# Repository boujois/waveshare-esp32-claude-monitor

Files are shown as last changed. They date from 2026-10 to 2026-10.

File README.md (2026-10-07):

# Waveshare ESP32 Claude Monitor

A tiny round desk display that tells you what [Claude Code](https://claude.com/claude-code) is up to, and taps you on the shoulder the moment it needs you. 👋

When a session is waiting for a permission, an answer or a plan approval, the screen lights up with a pulsing orange ring so you never leave Claude sitting idle. The rest of the time it shows which sessions are working, how much of your plan you've used, and what you've got done today.

<p align="center">
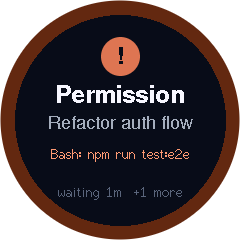
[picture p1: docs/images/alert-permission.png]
Permission alert: pulsing orange ring, 'Permission', session name and the command being requested
  
  &nbsp;
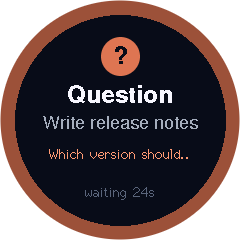
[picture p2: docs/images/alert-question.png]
Question alert: Claude is asking a question in the 'Write release notes' session
  
  &nbsp;
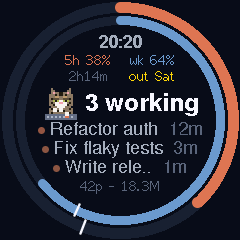
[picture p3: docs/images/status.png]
Status screen: time, plan usage rings with pace ticks, the cat typing beside '3 working', and a list of sessions with timers
  
  &nbsp;
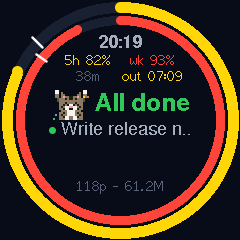
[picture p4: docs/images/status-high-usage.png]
Status screen with high usage: rings turn yellow and red, and the cat cheers beside 'All done'
  
</p>

<p align="center"><sub>Real screenshots, grabbed straight off the device (with made-up session names).</sub></p>

<p align="center"><b><a href="#install">⬇️ Install it: three ways, easiest first</a></b></p>

---

## Contents

- [What it shows](#what-it-shows)
- [What you'll need](#what-youll-need)
- [How it works](#how-it-works)
- [Install](#install)
  - [Option 1: Let Claude set it up (easiest)](#option-1-let-claude-set-it-up-easiest)
  - [Option 2: Download the installer (no coding)](#option-2-download-the-installer-no-coding)
  - [Option 3: Build it yourself, step by step](#option-3-build-it-yourself-step-by-step)
- [Updating](#updating)
- [Reading the screen](#reading-the-screen)
- [Configuration](#configuration)
- [Troubleshooting](#troubleshooting)
- [Privacy: what it reads and where data goes](#privacy-what-it-reads-and-where-data-goes)
- [Uninstalling](#uninstalling)
- [Also in this repo](#also-in-this-repo)
- [Project layout](#project-layout)
- [Credits](#credits)

---

## What it shows

**🟠 When Claude needs you**, the whole screen becomes an alert:

- **What kind of request it is:** *Permission*, *Question*, *Plan ready* or *Needs input*
- **Which session** is asking, by name
- **What it wants**, e.g. `Bash: npm run test:e2e`, or the question Claude is asking
- **How long it's been waiting**, and how many other sessions are waiting too

The alert clears itself as soon as you respond, so you don't need to touch the device. To hide it sooner, **double-tap the case**.

**⚪ The rest of the time**, you get a calm status screen:

- 🕐 The current time
- 🔶 **5-hour plan usage** (outer ring) and 🔷 **weekly plan usage** (inner ring), each with a countdown to its reset and a tick showing whether you're on pace
- **How many sessions are working**, plus up to three active ones, each with a status dot and how long it's been working
- 🐱 **A little tabby cat** beside the headline, acting out what's going on: typing while sessions work, waving when something needs you, cheering when they've finished, and curled up asleep when nothing's happening
- 📊 **Today's activity**: prompts sent and tokens processed, across every session
- 🔴 **Anthropic incidents**: when [Anthropic's status page](https://status.claude.com) reports a problem with Claude Code, the API or claude.ai, a red ring and the incident's name take the place of your plan usage, so you can tell when errors are on Anthropic's side

**🟢 While CI runs** on the pull request for the session you have open in the Claude app, the display shows its checks as a ring that fills in as they pass.

It works with every Claude Code session on your Mac: the desktop app, the terminal and IDE extensions. It can also alert you when a **regular chat in the Claude app** needs you, either to approve a connector or tool, or to answer a question Claude has asked (see [step 7](#7-optional-alerts-for-claude-app-chats)).

---

## What you'll need

| | |
|---|---|
| 🖥️ **The display** | [Waveshare ESP32-S3-LCD-1.28](https://www.waveshare.com/wiki/ESP32-S3-LCD-1.28): an ESP32-S3 with a 1.28" 240×240 round screen (GC9A01). The version with the CNC metal case ("-B") looks great on a desk. Get the **non-touch** version; the touch version uses different pins. |
| 🔌 **A USB-C cable** | For flashing, and for power afterwards. Once it's set up, any USB phone charger will do. |
| 🍎 **A Mac** | Running Claude Code. The helper uses `launchd` and the macOS Keychain. |
| 📶 **2.4 GHz Wi-Fi** | The ESP32 can't join 5 GHz-only networks. |
| 🌐 **Chrome or Edge** | For the one-click firmware installer. Safari and Firefox can't talk to USB devices. |
| 🐍 **Python 3** | For the Mac helper. macOS has it once Apple's Command Line Tools are installed; the installer offers to install them if needed. |
| 🐙 **Optional: the [GitHub CLI](https://cli.github.com)** | For the [CI card](#the-ci-card): `brew install gh`, then `gh auth login` |
| 🛠️ **[PlatformIO](https://platformio.org/install/cli)** | *Developers only*, to build the firmware yourself: `brew install platformio` |
| 🖨️ **Optional: a 3D printer** | To print a [desk stand](#-stand-3d-printable-desk-stands). You'll also want a right-angle USB-C cable. Four 8 × 2 mm button magnets are optional, if you'd like to stick the stand to a metal surface. |

---

## How it works

```mermaid
flowchart LR
    subgraph Mac["Your Mac"]
        CC["Claude Code sessions<br/>(desktop app, terminal, IDE)"]
        S["~/.claude/sessions/*.json<br/>(live session list)"]
        T["~/.claude/projects/**/*.jsonl<br/>(transcripts)"]
        B["Mac helper<br/>claude_status_bridge.py"]
        CC -- "hooks (async curl)" --> B
        CC -.writes.-> S
        CC -.writes.-> T
        S --> B
        T --> B
        CH["Claude app chats"]
        L["chat-window log<br/>(tool approvals)"]
        CH -.writes.-> L
        L --> B
        CH -- "claude-status connector<br/>(waiting_for_user)" --> B
    end
    A["Anthropic usage API<br/>(optional)"] --> B
    G["GitHub CI checks<br/>(via gh, optional)"] --> B
    SP["Anthropic status page<br/>(incidents)"] --> B
    B -- "POST /state over Wi-Fi<br/>(every second when changed)" --> D["Round display<br/>claude-status.local"]
```

There are three main moving parts, plus an extra for chats:

1. **Claude Code hooks** fire on events like *permission requested*, *question asked*, *tool finished* and *turn finished*. Each hook is a tiny background `curl` that forwards the event to the helper on `127.0.0.1`. The hooks are async, so they never slow Claude down, and they quietly do nothing if the helper isn't running.
2. **The Mac helper** (`claude-status/bridge/claude_status_bridge.py`) merges three sources into one small JSON summary:
   - **the hook events**, to work out who's waiting for you
   - **`~/.claude/sessions/`**, for which sessions are open and whether each is busy or idle
   - **your transcripts**, for today's token and prompt totals

   If you turn it on, it also checks your plan usage with Anthropic. If the GitHub CLI is signed in, it asks GitHub about the checks on the pull request for the session you have open in the Claude app. Every 2 minutes it checks Anthropic's status page for incidents. It pushes the summary to the display whenever something changes, plus a heartbeat every 10 seconds.
3. **The display firmware** (`claude-status/firmware/`) joins your Wi-Fi and announces itself as `claude-status.local`. It accepts the summary on `POST /state` and draws the right screen at about 30 fps.
4. **Chats in the Claude app** don't have hooks, so the helper uses two other signals. It watches the app's chat-window log for **tool approval prompts**. A tiny local **connector** (`chat_mcp.py`) also gives Claude a `waiting_for_user` tool, which it calls when a reply ends with a question for you.

---

## Install

There are three ways to install, easiest first:

| | Best for | You'll need |
|---|---|---|
| 🤖 **[Option 1: Let Claude set it up](#option-1-let-claude-set-it-up-easiest)** | Anyone who uses Claude Code | Claude Code: the Claude app's **Code** tab, or `claude` in a terminal |
| ⬇️ **[Option 2: Download the installer](#option-2-download-the-installer-no-coding)** | No coding, and no Claude Code needed | Google Chrome or Microsoft Edge |
| 🛠️ **[Option 3: Build it yourself](#option-3-build-it-yourself-step-by-step)** | Developers who want to change the code | PlatformIO and a terminal |

All three need the display, a USB-C **data** cable (many charging-only cables won't work) and a Mac.

---

## Option 1: Let Claude set it up (easiest)

Claude Code does the whole setup for you, using the [setup skill](.claude/skills/setup-claude-monitor/SKILL.md) included in this project:
- it checks your Mac and installs the tools it needs
- it flashes the display and walks you through Wi-Fi on your phone
- it sets up your Mac and tests everything end to end

It stops and tells you whenever a step needs you, such as clicking **Always Allow** on a Keychain prompt.

1. **Get the project.** Download **Source code (zip)** from the [latest release](https://github.com/boujois/waveshare-esp32-claude-monitor/releases/latest) and double-click it to unzip. If you use git, you can clone it instead:
   ```bash
   git clone https://github.com/boujois/waveshare-esp32-claude-monitor.git
   ```
2. **Plug the display into your Mac** with the USB-C cable.
3. **Open the folder in Claude Code:**
   - **Claude app:** open the **Code** tab and choose the unzipped folder as the project.
   - **Terminal:** `cd` into the folder and run `claude`.
4. **Say *"set up the display"*,** or type `/setup-claude-monitor`, then follow along.

Allow about 10 minutes. Claude flashes the published firmware, the same files as Option 2, so there's nothing to build unless you ask it to build from source. The rest follows the same steps as [Option 3](#option-3-build-it-yourself-step-by-step), so you can read along there.

---

## Option 2: Download the installer (no coding)

No coding, no command line, about 10 minutes. Use **Google Chrome** or **Microsoft Edge** for step 1.

### 1. Put the software on the display

Open the **[Claude Monitor installer](https://boujois.github.io/waveshare-esp32-claude-monitor/)** in Chrome or Edge. Plug the display into your computer, click **Install Claude Monitor**, choose the display from the list, then click **Install**. It takes about a minute.

<details>
<summary><b>The installer page doesn't open?</b> Use Espressif's web flasher instead</summary>

1. Download **`claude-monitor-firmware.bin`** from the [latest release](https://github.com/boujois/waveshare-esp32-claude-monitor/releases/latest).
2. Open [Espressif's web flasher](https://espressif.github.io/esptool-js/) in Chrome or Edge.
3. Click **Connect** and choose the display.
4. Set **Flash Address** to `0x0`, choose the `.bin` file, then click **Program**.
5. When it's done, unplug the display and plug it back in.
</details>

### 2. Connect the display to your Wi-Fi

The display now shows **Wi-Fi setup** with a QR code. On your phone, scan the code, or join the Wi-Fi network **`Claude-Monitor-Setup`**. A page pops up: pick your home Wi-Fi, type its password, and tap **Save**. The display connects and shows **"Waiting for Mac"**.

> 📶 The display only works with **2.4 GHz** Wi-Fi. If the page doesn't pop up, open `192.168.4.1` in your phone's browser.

**To change Wi-Fi later**, do any of these:
- unplug the display and plug it back in **3 times in a row**, each within 10 seconds of the last; the second time, it reminds you to do it once more
- run `curl -X POST http://claude-status.local/wifi/reset` on your Mac
- hold the **BOOT** button for 5 seconds, if your case leaves it reachable

If the display can't find its saved Wi-Fi, for example after moving house, it opens setup by itself.

### 3. Set up your Mac

1. Download **`Claude-Monitor-Mac.zip`** from the [latest release](https://github.com/boujois/waveshare-esp32-claude-monitor/releases/latest) and double-click it to unzip.
2. In the **Claude Monitor** folder, **right-click `Install.command` and choose Open**. macOS blocks double-clicking downloaded scripts the first time. If it still refuses, open **System Settings → Privacy & Security** and click **Open Anyway**.
3. Answer the questions in the window that opens. It asks before restarting the Claude app, and before turning on plan usage.
4. For chat questions, the installer copies one sentence to your clipboard. Paste it into **Claude → Settings → Profile → personal preferences**.

Within a few seconds the display switches to your Claude status. To remove everything later, right-click **`Uninstall.command`** and choose **Open**.

---

## Option 3: Build it yourself, step by step

For developers, or anyone who wants to see every step. Allow about 15 minutes. Most of that is PlatformIO downloading the ESP32 toolchain the first time.

### 1. Clone the repo

```bash
git clone https://github.com/boujois/waveshare-esp32-claude-monitor.git
cd waveshare-esp32-claude-monitor
```

### 2. Wi-Fi (optional for development)

You don't need to put your Wi-Fi details in the code: after flashing, set up Wi-Fi from your phone as in [Option 2, step 2](#2-connect-the-display-to-your-wi-fi). The display remembers it across re-flashes.

If you re-flash a lot and want to skip that step, you can pre-fill your Wi-Fi in a git-ignored `src/secrets.h`:

```bash
cp claude-status/firmware/src/secrets.h.example claude-status/firmware/src/secrets.h
```

It's only used when the board has no saved network, and release builds never include it.

### 3. Flash the display

Plug the board into your Mac with USB-C, then build and upload. PlatformIO finds the board by itself. If you have several boards plugged in, add `upload_port = /dev/cu.usbmodem…` to `platformio.ini`.

```bash
cd claude-status/firmware
pio run -t upload
```

The first build downloads the ESP32-S3 toolchain plus the [LovyanGFX](https://github.com/lovyan03/LovyanGFX) and [ArduinoJson](https://arduinojson.org/) libraries, so give it a few minutes. When it finishes, the display shows **Wi-Fi setup**, or **"Waiting for Mac"** if it already knows your Wi-Fi. 🎉

> 💡 **Tip:** `pio device monitor` shows the board's serial log, including `Wi-Fi connected, IP …` and `mDNS: claude-status.local`.

### 4. Install the Mac helper and hooks

```bash
cd ../bridge
./install.sh
```

This does three things:

- **Starts the helper as a background service** (`~/Library/LaunchAgents/com.claude-status.bridge.plist`). It starts when you log in and restarts itself if it ever crashes.
- **Adds the hooks to `~/.claude/settings.json`**, after saving a timestamped backup next to it. Your existing settings and hooks are left as they are. Ours are tagged with `CLAUDE_STATUS` so they can be found and removed cleanly later.
- **Adds the `claude-status` connector to the Claude app** (`claude_desktop_config.json`, also backed up first) for [chat alerts](#7-optional-alerts-for-claude-app-chats). The app overwrites that file while it's running, so if the app is open, the installer skips this step and tells you to run `./install-chat-connector.sh` from **Terminal.app** instead. That script quits the Claude app, adds the connector and reopens the app; your sessions are still there afterwards.

> ℹ️ The installer finds Python by itself (Homebrew's, or the one that comes with Apple's Command Line Tools). To use a specific one, run `PYTHON=/path/to/python3 ./install.sh`.

Within a couple of seconds the display should switch from *"Waiting for Mac"* to the status screen. New Claude Code sessions pick up the hooks automatically, and most already-open sessions do too.

### 5. Try it out ✅

Ask Claude something that needs your approval, or just ask it to *"ask me a question"*. The display should light up orange straight away, and go back to normal when you answer.

### 6. (Optional) Turn on plan usage rings

The rings show your 5-hour and weekly plan limits, the same numbers as Claude Code's `/usage` screen. They use the sign-in of the **terminal** `claude` command. The desktop app keeps its own separate sign-in, so you need to sign the terminal in once.

**a. Sign the terminal in.** This opens your browser:

```bash
claude auth login
```

**b. Switch plan usage on and restart the helper:**

```bash
echo '{"plan_usage": true}' > config.json
```
```bash
launchctl kickstart -k gui/$(id -u)/com.claude-status.bridge
```

**c. Allow Keychain access.** macOS will ask whether `security` can read **"Claude Code-credentials"**. Click **Always Allow**. If you click plain *Allow*, it will ask again after every restart.

The rings fill in within a few seconds and refresh every 5 minutes.

**Keeping it signed in:** the sign-in token expires every few hours. When it does, the helper asks the `claude` command to renew it by sending one tiny prompt (`ok`) on Haiku. That prompt runs with no tools, connectors, hooks or saved session, so it uses a negligible sliver of your plan. You'll see `plan usage: token renewed` in the log when it happens. You should only need `claude auth login` again if you sign out, or if the sign-in is revoked.

> 🔒 The token is only ever sent to `api.anthropic.com`. The helper never refreshes, rewrites or logs it. Renewal is done by the `claude` command itself.

> 💡 **Why not a long-lived `claude setup-token` token?** We tried: Anthropic accepts those tokens but refuses them for plan usage (HTTP 403).

### 7. (Optional) Alerts for Claude app chats

Regular chats in the Claude app (the **Chat** tab, not Claude Code) can light up the display too. There are two kinds of alert.

**🔐 Tool approvals work automatically.** When a chat shows an **Allow** button for a connector or tool, the display shows **Permission → Claude chat → "Allow Weather: get_forecast?"**. There's nothing to set up.

**❓ Questions need one line in your Claude settings.** The `claude-status` connector from step 4 gives Claude a `waiting_for_user` tool. To make sure Claude uses it:

1. Make sure the connector is installed. If `install.sh` said the Claude app was running, run this from **Terminal.app**, not a terminal inside the Claude app:

   ```bash
   ./install-chat-connector.sh
   ```
2. Open **Settings → Profile**, and add this to *"What personal preferences should Claude consider in responses?"*:

   > When a reply ends with a question for me, or you need me to choose or decide something before you can continue, call the claude-status `waiting_for_user` tool as the last step, with a short version of the question and a 2-5 word title for the chat.

3. The first time Claude calls it, choose **Always allow**.

The display then shows **Question → *chat title* → *the question***.

**How chat alerts clear:** the app doesn't report when you've answered, so a chat alert clears in any of these cases:
- when you **switch to the Claude app**
- after the app has been **in front for 30 seconds**, if you were already in it
- when the chat's **next tool runs** without needing approval (approval alerts only)
- **after 10 minutes**, as a backstop

> ⚠️ **Good to know:**
> - Question alerts rely on Claude choosing to call the tool. That's usually reliable, but not guaranteed.
> - Tool approvals are read from the app's internal log, so an app update could quietly change or break them.
> - Neither works for claude.ai open in a web browser.

---

## Updating

When a new version comes out, the display's footer alternates with **"Update: v1.x.x"**. The helper checks GitHub once a day. To update, do any of these:

- **Ask Claude Code** *"update my Claude monitor"*. The installer adds an `update-claude-monitor` skill to Claude Code, so this works in any session.
- **Double-click** `Update.command` from the Mac zip; the first time, right-click it and choose **Open**.
- **Run** `"$HOME/Library/Application Support/Claude Monitor/update.sh"` in a terminal. Add `--check` to only see the versions.

It updates the Mac helper, keeping your settings, and sends the new firmware to the display **over Wi-Fi**. No cable is needed; the display shows a progress ring and restarts by itself.

> 🔐 **Pairing:** the first time the helper finds the display, they pair with a random key. After that, only your Mac can update the display. To pair with a different Mac, power the display on 3 times in a row, each within 10 seconds of the last. That resets its Wi-Fi and pairing.

> ⚠️ **Coming from v1.0.x?** Older displays can't update over Wi-Fi yet, and older Mac installs don't have `update.sh`. Do one last manual update: re-flash from the [installer page](https://boujois.github.io/waveshare-esp32-claude-monitor/), which keeps your Wi-Fi, and run `Install.command` from the new zip. Every update after that is automatic.

---

## Reading the screen

### The status screen

Status screen

From top to bottom:

- **Rings:** the outer 🔶 ring is your 5-hour plan usage and the inner 🔷 ring is weekly usage. They fill clockwise from 12 o'clock. The small white **tick** on each ring shows how much of that window has gone by. If the coloured arc is past its tick, you're using your plan faster than it lasts. While Anthropic has an incident affecting Claude Code, the API or claude.ai, the usage rings make way for a pulsing **red** ring, and *Anthropic incident* shows where the usage numbers were, with the incident's name scrolling underneath, e.g. *Elevated errors for Claude Opus 5.5*. Red error dots are then most likely Anthropic's problem, not yours.
- **Time:** the current time, kept in sync over the internet (NTP).
- **`5h 38%` / `wk 64%`:** the same usage as numbers, with the time left until each limit resets underneath. When you're ahead of the tick, it shows in yellow when you'd run out at this pace instead: `out 16:40`, or `out Fri` for the weekly limit.
- **Headline**, with [the cat](#the-cat) acting it out beside it:
  - **`2 working`:** sessions are busy
  - **`All done`** (green): sessions have finished; you'll usually see the green Done card instead
  - **`All idle`:** nothing is happening
  - **`1 waiting`** (pulsing orange): you dismissed an alert, but something still needs you
- **Session list:** up to three active sessions, each with a dot (see the colour guide below). Working sessions show how long they've been working, e.g. `12m`.
- **Footer:** today's prompt count and total tokens processed, across all sessions.

<br clear="right">

### The cat

<p align="center">The cat's five moods: typing at a keyboard, waving a paw, cheering with its paws in the air, seeing stars, and curled up asleep</p>

A brown tabby sits beside the headline on the status screen and acts out what your sessions are up to:

| The cat is… | When |
|---|---|
| ⌨️ **Typing** | Sessions are working (`2 working`). The more there are, the faster it types. |
| 👋 **Waving** | Something still needs you after you hid its alert (`1 waiting`) |
| 🎉 **Cheering** | Sessions have finished and you haven't replied yet (`All done`) |
| 💫 **Seeing stars** | A session's last turn ended with an API error, and nothing is working or waiting |
| 💤 **Asleep** | Nothing is happening (`All idle`), or the display hasn't heard from your Mac |

When the display powers on, the cat walks across the empty screen before anything else appears.

Prefer the plain status screen? Set `"cat": false` in the helper's `config.json` (see [Configuration](#configuration)). The display remembers it, so the walk at power-on stops too.

### The alert screen

Question alert

| Headline | Badge | Shown when… |
|---|---|---|
| **Permission** | `!` | Claude wants to run a tool that needs your approval |
| **Question** | `?` | Claude is asking you a multiple-choice question, or its reply ends waiting on you: a question (*"Want me to push it?"*), a request (*"After you approve, I'll create the ticket"*), or a step for you to do (*"Run it on staging and paste the output"*) |
| **Plan ready** | `!` | Claude has finished a plan and wants you to review it |
| **Needs input** | `!` | an MCP server or agent needs something from you |

If several sessions are waiting, the one that has waited longest is shown, and the footer says `+N more`.

**Want it to go away?** Double-tap the case: two quick, firm taps with a fingertip, anywhere on the case. A short press of the **BOOT** button does the same, if your case leaves it reachable. That hides the alert until a *new* request comes in, and the status screen then shows `N waiting` in orange instead.

Double tap uses the board's built-in motion sensor. Typing, putting a mug down or knocking on the desk doesn't set it off, and neither does picking the display up.

<br clear="right">

### The Done card

When a Claude Code session finishes and doesn't need anything from you, the display shows a green **Done** card: a ✓, the session's name, a one-line summary of what it did (from the [reply check](#how-replies-that-need-you-are-spotted)), and how long ago it finished. The card stays until you send that session another message, so you can see at a glance that a task is finished. If several sessions have finished, the most recent is shown with `+N more`.

The card goes away when:
- **you reply** to that session
- **you look at it:** open that session in the Claude app, with the app in front
- **you were already watching:** if the session finishes while it's open in front of you, no card appears
- **you double-tap the case** (or press **BOOT**): the sessions on the card stay hidden, and a session that finishes later still gets its own card

A quick acknowledgement like *"thanks"*, *"ok"* or 👍 doesn't bring the card back when Claude answers it.

Needs-input alerts always come first. If you'd rather finished sessions faded back to the status screen after a while, set `done_window` in `config.json`, for example `900` for 15 minutes.

### The CI card

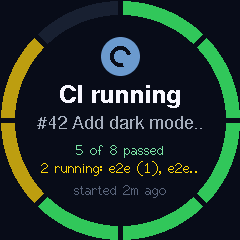
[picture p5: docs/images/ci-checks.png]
CI card: a ring of eight checks, five passed, two running and one queued


When the session you have open in the Claude app is on a branch with an open pull request, the display shows that pull request's checks. The ring has one segment per check and fills clockwise as they pass: 🟢 passed, 🔴 failed, 🟡 running (pulsing), dark for queued and grey for cancelled. Checks that were skipped are left out. Underneath, it says how many have passed, which ones are running or failed, and when the run started or finished.

It follows the session you last opened in the Claude app, so it stays up while you switch to another app to wait. A question or permission request from **another** session still comes first. The CI card then comes before the open session's own requests, which you can see in the app anyway, and before Done cards.

Passed checks stay on screen for 10 minutes, then the status screen comes back (`ci_passed_window` in `config.json`). Failed checks stay until you push again. Double-tap to hide the card until the checks change.

The helper asks GitHub with the [GitHub CLI](https://cli.github.com) (`gh`), every 15 seconds while checks run and every minute otherwise, so `gh` needs to be installed and signed in. Sessions in the terminal or an IDE don't get a CI card: only the Claude app tells the helper which session you have open.

<br clear="right">

### How replies that need you are spotted

When a Claude Code turn ends, the helper reads Claude's final message:

1. **Phrase check.** If the message ends with a question, or a request like *"after you approve"*, *"please confirm"*, *"should I…"* or *"over to you"*, the display shows a **Question** alert straight away.
2. **Haiku check.** If the phrases don't catch it, the helper asks Claude Haiku, through the terminal `claude` command, whether the message is waiting on you, and gets a one-line summary for the display. Each check takes a few seconds and uses a sliver of your plan.

The Haiku check needs the terminal `claude` command to be signed in, the same as the [plan usage rings](#6-optional-turn-on-plan-usage-rings). Without that sign-in, only the phrase check runs. To turn the Haiku check off, set `"check_replies": false` in `config.json`. When the helper starts, it also checks idle sessions from the last 24 hours, so nothing is missed after a restart.

### Colour guide

| Colour | Meaning |
|---|---|
| 🟠 Orange dot (pulsing) | Session is working |
| 🟠 Orange dot (solid) | Session is waiting for you |
| 🟢 Green card / dot | Session finished, and you haven't replied to it yet |
| 🔴 Red dot | Session's last turn ended with an API error |
| 🟡 Yellow ring | Usage is 75% or more |
| 🔴 Red ring | Usage is 90% or more. Time to pace yourself! |
| ⚪ White tick on a usage ring | How much of that window has gone by. Usage past its tick will run out before the reset. |
| 🟡 `out 16:40` | When you'd run out at your current pace |
| 🟢 🔴 🟡 Ring segments | CI checks passed, failed or running, on the [CI card](#the-ci-card) |
| 🔴 Red ring (pulsing) instead of the usage rings | Anthropic has an incident affecting Claude Code, the API or claude.ai |

### Other screens

- **Waiting for Mac:** the display has never heard from the helper since it powered on. It shows its IP address and `claude-status.local` to help with debugging.
- **Mac offline:** nothing has arrived for 30 seconds. Your Mac might be asleep, or the helper might have stopped. The cat naps on both of these screens until the Mac is back.
- **Wi-Fi setup:** the display has no saved Wi-Fi, or can't reach it. Join `Claude-Monitor-Setup` from your phone. See [Option 2, step 2](#2-connect-the-display-to-your-wi-fi) for how to bring this screen back to change networks.
- **Diagnostics:** tap the case **5 times** quickly. It shows the firmware version, the Wi-Fi network and its signal strength, the IP address and name, when the Mac last sent an update, and how long the display has been on. The ring counts down for 30 seconds, then it closes by itself. Double-tap to close it sooner.

---

## Configuration

### Mac helper: `claude-status/bridge/config.json`

All keys are optional, and this file is git-ignored. Restart the helper after changing it:

```bash
launchctl kickstart -k gui/$(id -u)/com.claude-status.bridge
```

| Key | Default | What it does |
|---|---|---|
| `device_host` | `"claude-status.local"` | Hostname or IP of the display |
| `plan_usage` | `false` | Fetch 5-hour/weekly plan usage (see [step 6](#6-optional-turn-on-plan-usage-rings)) |
| `plan_usage_interval` | `300` | Seconds between plan usage checks |
| `push_interval` | `1.0` | How often (seconds) the helper checks for changes |
| `heartbeat_interval` | `10` | Push at least this often (seconds), even if nothing changed |
| `done_window` | `0` | How long (seconds) a finished session shows as done (the green card). `0` keeps it until you reply |
| `chat_alerts` | `true` | Alert on Claude app chats (tool approvals and connector questions) |
| `check_replies` | `true` | When a Claude Code reply doesn't obviously ask for anything, ask Haiku whether it's waiting on you (see [How replies that need you are spotted](#how-replies-that-need-you-are-spotted)) |
| `ci_checks` | `true` | Show the [CI card](#the-ci-card) for the session you have open in the Claude app. Needs the GitHub CLI (`gh`), signed in |
| `ci_passed_window` | `600` | How long (seconds) checks that passed stay on screen. `0` keeps them while the session is open |
| `status_page` | `true` | Check [Anthropic's status page](https://status.claude.com) every 2 minutes, and turn the ring red during incidents affecting Claude Code, the API or claude.ai |
| `cat` | `true` | Show [the cat](#the-cat). `false` brings back the plain status screen, and the display stops walking the cat across at power-on |
| `listen_port` | `47823` | Local port for hooks. If you change it, also update the URL in `hooks.py` and re-run `install.sh` |

### Firmware: top of `claude-status/firmware/src/main.cpp`

| Setting | Default | What it does |
|---|---|---|
| `HOSTNAME` | `"claude-status"` | mDNS name: the display is reachable at `<HOSTNAME>.local` |
| `SETUP_AP` | `"Claude-Monitor-Setup"` | Name of the Wi-Fi setup network |
| `DEFAULT_TZ` | `"UTC0"` | Timezone until the Mac helper connects. After that, the display uses your Mac's timezone automatically. |
| `STALE_MS` | `30000` | How long (ms) without an update before showing *Mac offline* |
| `TAP_G` | `0.25` | How firm each tap on the case must be, in g. Raise it if knocks on your desk dismiss alerts; lower it if your taps are missed. |
| `DIAGNOSTICS_MS` | `30000` | How long (ms) the diagnostics screen stays up after 5 quick taps |
| Brightness | `150` / `255` | Status screen / alert brightness, set at the end of `loop()` |

Re-flash after changing anything with `pio run -t upload`.

---

## Troubleshooting

<details>
<summary><b>The display is stuck on "Waiting for Mac"</b></summary>

1. Is the helper running? `launchctl print gui/$(id -u)/com.claude-status.bridge | grep state` should say `running`.
2. Check its log: `tail -20 ~/Library/Logs/claude-status-bridge.log`. Look for `pushing to claude-status.local (192.168.x.x)`.
3. If it says `cannot resolve claude-status.local`, mDNS isn't getting through your network. Set `"device_host"` in `config.json` to the IP address shown on the display. A DHCP reservation in your router keeps that IP from changing.
4. Make sure your Mac and the display are on the same network. Guest networks often block devices from seeing each other.
</details>

<details>
<summary><b>Claude is waiting but the display doesn't alert</b></summary>

1. Check the hooks are installed: `jq '.hooks | keys' ~/.claude/settings.json` should list `PermissionRequest`, `PreToolUse`, `Notification` and the others.
2. Check events are arriving: `curl -s http://127.0.0.1:47823/state | jq .hook_events_seen` should increase as you use Claude.
3. The helper logs every change to who's waiting, e.g. `9a8ac88a PermissionRequest: waiting - -> ['perm']`.
4. Sessions that were already open before you installed may need restarting to pick up the hooks.
</details>

<details>
<summary><b>An alert won't go away</b></summary>

Alerts clear when the tool finishes, when you send a new prompt, or when Claude's turn ends. If you deny a permission and Claude stops quietly, the alert clears when that turn ends. You can also double-tap the case to dismiss it, or press **BOOT** if your case leaves the button reachable.
</details>

<details>
<summary><b>Double-tapping doesn't dismiss anything</b></summary>

1. Tap the metal case twice with a fingertip, firmly, with the second tap within about half a second of the first. Stop at two: three or four taps in a row don't count. It works on the alert, the CI card and the Done card; the status screen ignores it.
2. Open `http://claude-status.local/` in a browser. `taps seen` counts the double taps and 5-tap runs the display noticed. If it says `no motion sensor`, your board doesn't have one, or it isn't answering.
3. If light taps are missed, or knocks on your desk count, change `TAP_G` in the [firmware settings](#configuration) and re-flash.
</details>

<details>
<summary><b>The CI card doesn't appear</b></summary>

1. It only shows for the session you have open in the **Claude app**, not the terminal or an IDE, and only while that session's branch has an **open** pull request with checks.
2. Passed checks stay for 10 minutes after they finish. To keep them up while the session is open, set `"ci_passed_window": 0` in `config.json`.
3. In that session's folder, `gh pr view --json statusCheckRollup` should list the checks. If `gh` isn't installed, run `brew install gh`. If it says you aren't signed in, run `gh auth login`.
4. The helper logs each change, e.g. `CI #1252 Fix the login form: running PPPRRQ`.
</details>

<details>
<summary><b>The ring is red and my usage is gone</b></summary>

Anthropic's [status page](https://status.claude.com) is reporting an incident that affects Claude Code, the Claude API or claude.ai; its name scrolls under *Anthropic incident* at the top of the status screen. The ring goes back to normal once Anthropic marks the incident resolved. Incidents that only affect other services, such as the Console, don't count. If the helper can't reach the status page for 10 minutes, it stops showing the incident, so a problem with your own connection isn't blamed on Anthropic.
</details>

<details>
<summary><b>The usage rings are empty</b></summary>

- Is `plan_usage` set to `true` in `config.json`? Did you restart the helper afterwards?
- `tail ~/Library/Logs/claude-status-bridge.log`:
  - **`no usable token` / `token rejected`:** run `claude auth login` in a terminal. The helper picks it up within 5 minutes.
  - **`renewal call failed`:** the helper couldn't run `claude`. Check that `claude -p ok` works in a terminal.
  - **`keychain read failed`:** you clicked *Deny* on the Keychain prompt. Restart the helper and click **Always Allow**.
- Plan usage is only available for Claude Pro and Max subscriptions.
</details>

<details>
<summary><b>Chat alerts don't appear</b></summary>

- **Questions:**
  - Check that `claude-status` appears in the chat's connectors (search and tools) menu. If it doesn't, run `./install-chat-connector.sh` from Terminal.app. Editing the config while the app is open doesn't stick.
  - Is the line in your personal preferences? Try asking a chat to *"ask me a question"*.
  - The helper logs `chat: question from …` when the tool is called.
- **Tool approvals:** the helper logs `chat: approval needed for …`. If that never appears, an app update may have changed the log format.
</details>

<details>
<summary><b>Colours look wrong, or the screen is blank</b></summary>

- **Inverted colours** (white background): flip `cfg.invert` in the `LGFX` class in `main.cpp`.
- **Blank screen:** double-check you have the **non-touch** ESP32-S3-LCD-1.28. The touch version uses different reset and backlight pins (RST 14, BL 2).
</details>

<details>
<summary><b>Upload fails with "port is busy" or "no serial data received"</b></summary>

Close anything else using the serial port, such as `pio device monitor` or the Arduino IDE. If it still won't connect, hold **BOOT**, tap **RESET**, release **BOOT**, then upload again.
</details>

### Handy debugging tools 🔧

| What | How |
|---|---|
| See exactly what the helper is sending | `curl -s http://127.0.0.1:47823/state \| jq` |
| One-off snapshot without the service | `python3 claude-status/bridge/claude_status_bridge.py --once` |
| Screenshot of the display | Open `http://claude-status.local/screen.bmp` in a browser |
| Display's own status page, including the taps it has seen | `http://claude-status.local/` |
| Diagnostics on the display itself: version, Wi-Fi, IP | Tap the case 5 times quickly |
| Helper log | `tail -f ~/Library/Logs/claude-status-bridge.log` |

---

## Privacy: what it reads and where data goes

It's your Claude activity, so here's exactly what this project touches:

- **Hooks** send event data (session ID, tool name and tool input such as the command being run) **only to `127.0.0.1`**, the helper on your own Mac.
- **The helper reads** `~/.claude/sessions/` (session names and busy/idle state) and your transcript files in `~/.claude/projects/` (token counts and prompt *counts* only; it doesn't keep your messages).
- **The display receives** session names, short details such as `Bash: npm test`, counts and usage percentages, over your local Wi-Fi.
- **Chat alerts:** the helper reads the Claude app's chat-window log (`~/Library/Logs/Claude/claude.ai-web.log`), but only the tool approval lines, which contain a tool name. The connector sends the short question and chat title Claude gives it to the helper on `127.0.0.1`, and from there to the display.
- **Reply checks:** when a Claude Code turn ends without an obvious question, the last 3,000 characters of Claude's reply are sent to Claude Haiku, through your own `claude` sign-in, to ask whether it's waiting on you. Turn this off with `"check_replies": false`.
- **Plan usage (opt-in only)** reads the terminal `claude` login's token from your Keychain and sends it **only to `api.anthropic.com`**. When the token expires, the helper runs one tiny `claude -p ok` request so the CLI renews it.
- **CI checks:** for the session you have open in the Claude app, the helper runs `gh pr view` in that session's folder, which asks **GitHub** about the branch's pull request using your own `gh` sign-in. The display gets the pull request's number and title, and the names and results of its checks. Turn this off with `"ci_checks": false`.
- **Anthropic's status page:** every 2 minutes the helper downloads the public summary from `status.claude.com`. The request carries nothing about you or your sessions. Turn this off with `"status_page": false`.
- **Nothing else leaves your Mac.** There's no telemetry, cloud service or account.

- **Updates:** the helper checks GitHub's public API for the latest release once a day. Firmware updates only go from your Mac to the display, using the pairing key in `config.json`.

> ⚠️ Apart from firmware updates, which need the pairing key, the display's web endpoints have no password. Anyone on your local network could read the screenshot, push fake status to it or reset its Wi-Fi. That's fine on a home network, but think twice on shared or office Wi-Fi.

---

## Uninstalling

```bash
./claude-status/bridge/uninstall.sh
```

This stops and removes the background service, takes our hooks back out of `~/.claude/settings.json`, removes the `claude-status` connector from the Claude app and the `update-claude-monitor` skill. It saves backups first, and leaves your other hooks and connectors alone. The display then shows *Mac offline* until you re-flash it with something else.

Also remove the `waiting_for_user` line from your Claude personal preferences. To sign the terminal out as well, run `claude auth logout`.

---

## Also in this repo

### 🖨️ `stand/`: 3D-printable desk stands

Desk stands for the CNC-cased display, ready to print. They all hold the screen at the same 75° angle and height, and all leave room for a **right-angle USB-C cable**: the plug sits under the case and the cable runs back through the stand and out of the back.

**Nine designs** live in `stand/designs/`. They all use the same ring position, angle and cable route, so any of them fits the same way:

| Design | Style | Printing |
|---|---|---|
| `1-halo` | Ultra modern: the screen floats on two curved arms over a thin round base | Needs supports under the ring and arms |
| `2-pebble` | Organic: the screen sunk into a smooth dome | Like `9-automotive` |
| `3-fin` | Minimal: two thin fins on a flat plate, with the cable hidden in a tunnel between them | A little support under the ring |
| `4-facet` | Angular: a low-poly crystal | Like `9-automotive` |
| `5-trestle` | Angular open frame: square bars like a small easel | A little support under the ring |
| `6-print` | Made for printing: a tapered arch | **No supports.** Print `6-print-print-on-back.stl` lying on its back |
| `7-inset` | The screen sits flush in a solid wedge | Almost no supports |
| `8-bend` | A round column that bends forward to hold the screen flush; the cable is hidden inside | Needs supports under the bend |
| `9-automotive` | A ring that cups the case on a domed base, with a hood over the cable tunnel. It sits low, with 1 mm of plastic under the tunnel where the cable leaves | Some support under the ring and hood |

<p align="center">
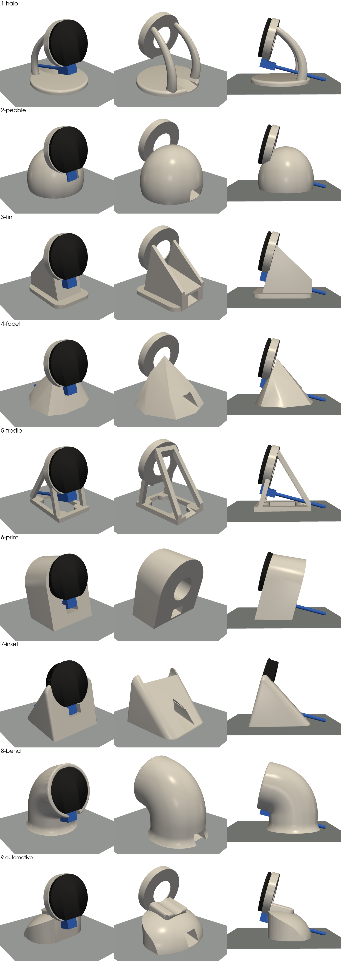
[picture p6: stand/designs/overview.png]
All nine stand designs, each shown from the front with the display, from the back, and from the side
  
</p>

**Fitting the display:** plug the right-angle cable into the case first, with the cable pointing backwards. Thread the far end of the cable through the stand's tunnel from the front (Halo and Trestle are open, so just lay the cable through), then push the case straight back into the ring. USB-C plugs are reversible, so flip the plug over if the cable points forwards. Cables that bend sideways won't fit.

**🧲 Magnets (optional):** to stick a stand to a metal surface, glue four **8 × 2 mm neodymium button magnets** into the pockets in its underside. The stands work fine without them. Each pocket is 8.4 mm wide and 2.2 mm deep. That's a smooth fit with room for glue, and each magnet sits just below the base, so it won't scratch whatever the stand is on. Set `MAGNETS = False` in `make_stand.py` to print the stands without the pockets.

**Changing a design:** `make_stand.py` builds `9-automotive` and defines the shared ring, and `designs.py` builds the others around it. All the sizes are settings in the scripts: the angle, the fit around the case, the tunnel size and the magnets.

```bash
pip install manifold3d trimesh numpy
cd stand
python3 make_stand.py     # writes designs/9-automotive.stl
python3 designs.py        # writes designs/*.stl and prints fit, stability and overhang checks
```

> 📏 The case and USB-C port positions were estimated from product photos, and the fit was checked against a model of a typical right-angle plug. Measure your own case and cable before printing.

---

## Project layout

```
.
├── claude-status/
│   ├── bridge/                      # Mac helper (Python, stdlib only)
│   │   ├── claude_status_bridge.py  # collects state, serves hooks, pushes to the display
│   │   ├── chat_mcp.py              # connector for Claude app chats (waiting_for_user tool)
│   │   ├── desktop_config.py        # adds/removes the connector in the Claude app config
│   │   ├── install-chat-connector.sh # quits Claude, adds the connector, reopens Claude
│   │   ├── update.py / update.sh    # updates the helper and the display (over Wi-Fi)
│   │   ├── update-skill.md          # the update-claude-monitor skill the installer adds
│   │   ├── hooks.py                 # adds/removes hooks in ~/.claude/settings.json
│   │   ├── install.sh               # launchd agent + hooks + connector
│   │   └── uninstall.sh
│   ├── package/                     # what users download
│   │   ├── Install.command          # double-click Mac installer
│   │   ├── Update.command
│   │   ├── Uninstall.command
│   │   └── web/index.html           # browser installer page (ESP Web Tools)
│   └── firmware/                    # ESP32-S3 firmware (PlatformIO + Arduino)
│       ├── platformio.ini
│       └── src/
│           ├── main.cpp
│           ├── cat.cpp / .h         # the tabby on the status screen: pixel-art poses and animations
│           ├── taps.cpp / .h        # taps on the case (double tap, 5 taps), via the motion sensor
│           └── secrets.h.example
├── tools/build-release.sh           # builds dist/: firmware, Mac zip, installer page
├── .github/workflows/release.yml    # on a v* tag: build, publish release + installer page
├── stand/                           # 3D-printable desk stands
│   ├── make_stand.py                # shared ring + design 9 -> designs/9-automotive.stl
│   ├── designs.py                   # designs 1-8 -> designs/*.stl
│   └── designs/                     # ready-to-print STLs and preview images
└── docs/images/                     # screenshots used in this README
```

---

## Credits

- [LovyanGFX](https://github.com/lovyan03/LovyanGFX) for fast, anti-aliased graphics on the GC9A01
- [ArduinoJson](https://arduinojson.org/) for parsing JSON on the ESP32
- [Waveshare](https://www.waveshare.com/) for a lovely little round display
- Built with [Claude Code](https://claude.com/claude-code), which now has a way to get your attention. 🧡

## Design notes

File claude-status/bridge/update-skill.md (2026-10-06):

---
name: update-claude-monitor
description: Update Claude Monitor, the round ESP32-S3 desk display that shows Claude Code status, to the latest release. Updates the Mac helper and the display's firmware (over Wi-Fi). Use when someone asks to update, upgrade or check the version of their Claude Monitor, Claude status display or desk display, or when the display shows "Update" with a version number.
---

# Update Claude Monitor

Claude Monitor's Mac helper lives in `~/Library/Application Support/Claude Monitor`. Its updater checks GitHub for the latest release, then updates the Mac helper (keeping `config.json`) and sends new firmware to the display over Wi-Fi.

1. **Check what's installed:**
   ```bash
   "$HOME/Library/Application Support/Claude Monitor/update.sh" --check
   ```
   It prints the latest release, the Mac helper's version and the display's version. If the folder doesn't exist, Claude Monitor isn't installed (or was installed from a git checkout). Point them to https://github.com/boujois/waveshare-esp32-claude-monitor#install.

2. **Update:** if anything is behind, tell them what will change, then run:
   ```bash
   "$HOME/Library/Application Support/Claude Monitor/update.sh"
   ```
   Use a timeout of at least 5 minutes. The display shows an "Updating" progress ring and restarts by itself; tell them not to unplug it meanwhile.

3. **Read the result and help with anything that didn't finish:**
   - **"needs USB":** the display runs firmware from before Wi-Fi updates (older than v1.1.0). 🙋 They open https://boujois.github.io/waveshare-esp32-claude-monitor/ in Chrome or Edge, plug the display into the Mac and click **Install**. Saved Wi-Fi is kept. After that, updates go over Wi-Fi.
   - **"paired with a different Mac":** 🙋 they power the display on 3 times in a row, each within 10 seconds of the last. That resets its Wi-Fi and pairing. They then redo Wi-Fi setup from their phone (join `Claude-Monitor-Setup`), and you run the update again.
   - **"Can't reach the display":** check it's powered and shows the status screen, not "Wi-Fi setup". Then try `curl -s http://claude-status.local/info`.
   - **"developer install":** the helper runs from a git checkout. Update it with `git pull` and that checkout's `claude-status/bridge/install.sh`.

4. **Confirm:** run `update.sh --check` again. Both versions should match the latest release. The display's "Update" notice disappears within a minute.

Never read or print `config.json`'s `device_key`; it's the display's pairing key.

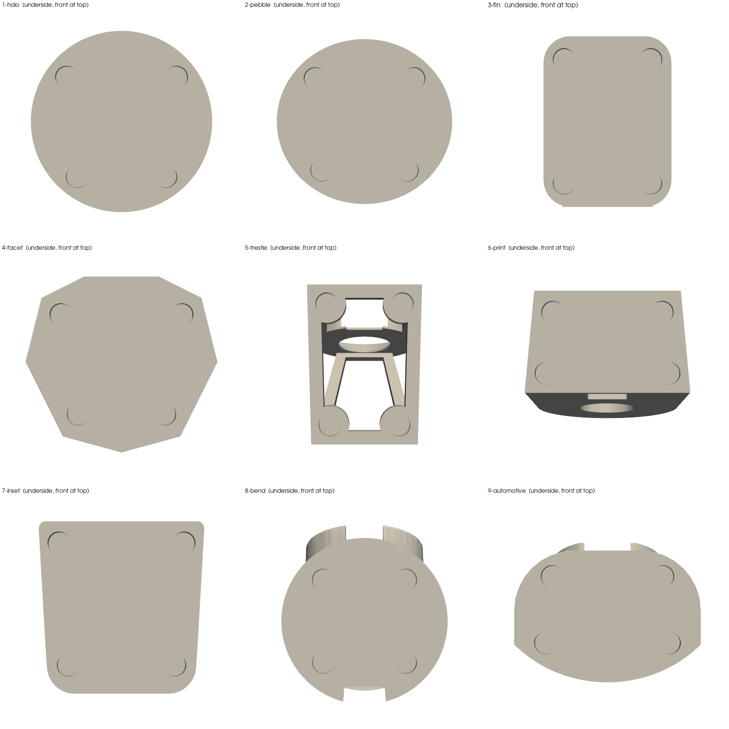
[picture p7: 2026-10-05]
stand/designs/magnets-undersides.png

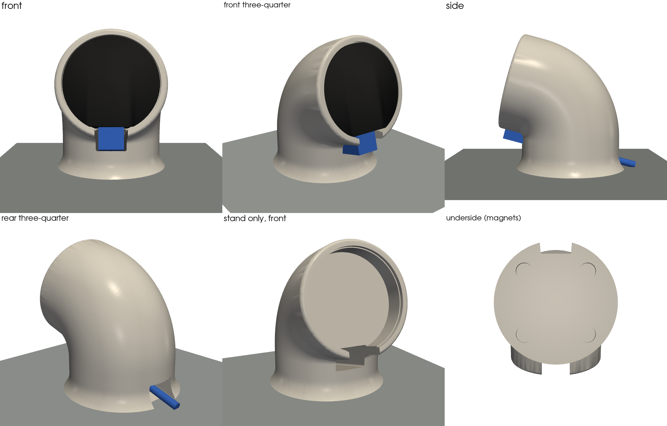
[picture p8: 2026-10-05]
stand/designs/8-bend.png

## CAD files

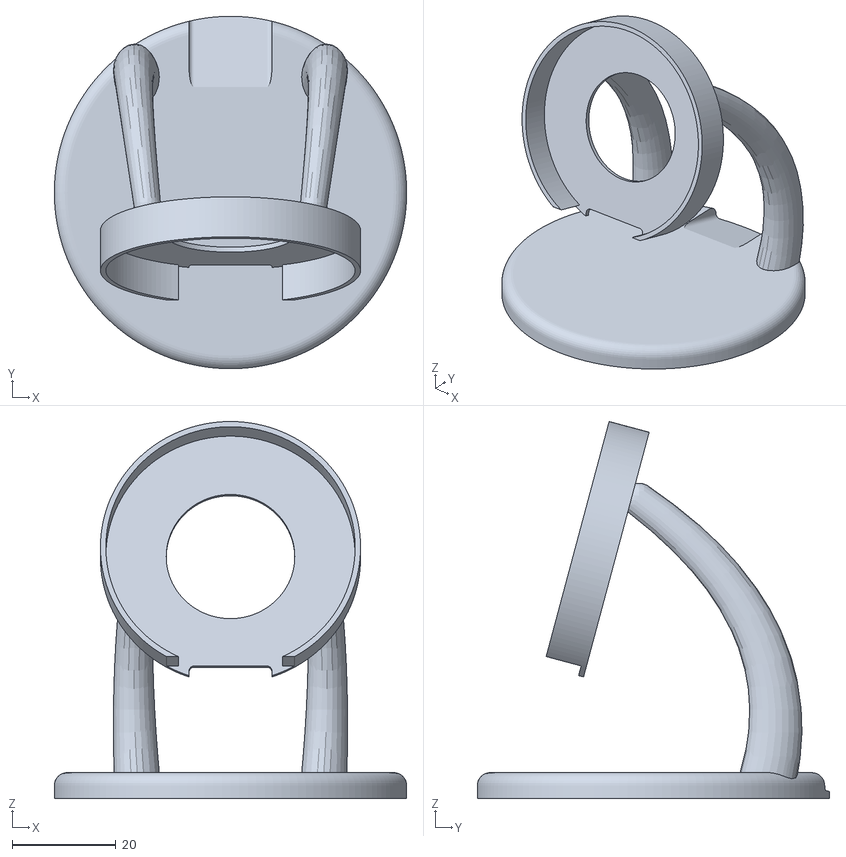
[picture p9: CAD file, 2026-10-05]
stand/designs/1-halo.stl
68.0 x 68.0 x 72.7

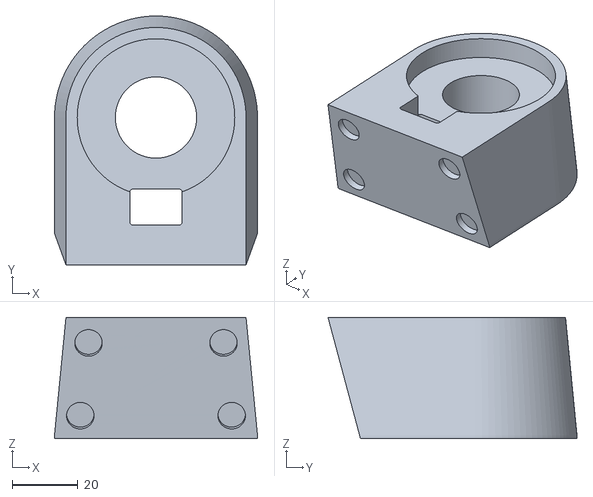
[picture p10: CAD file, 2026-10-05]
stand/designs/6-print-print-on-back.stl
62.0 x 76.0 x 37.0

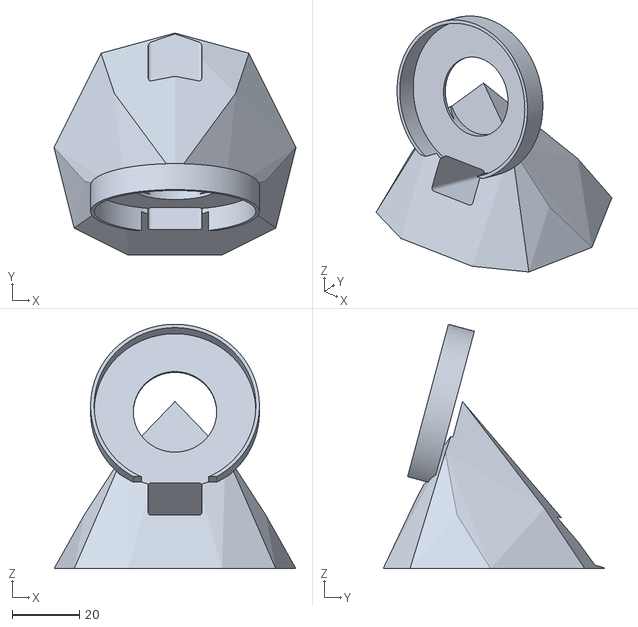
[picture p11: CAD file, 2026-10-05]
stand/designs/4-facet.stl
72.0 x 66.0 x 72.7

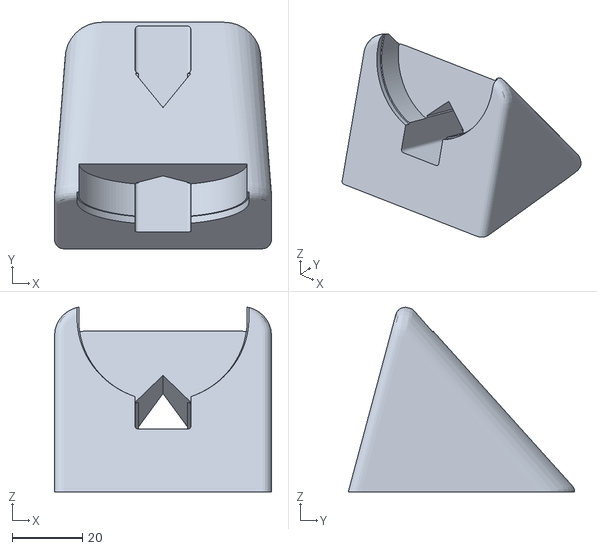
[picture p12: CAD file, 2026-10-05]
stand/designs/7-inset.stl
62.0 x 64.7 x 52.8

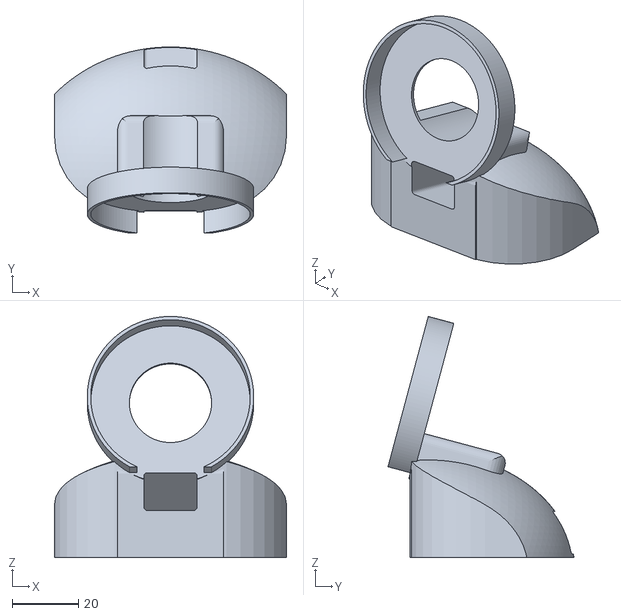
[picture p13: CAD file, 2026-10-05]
stand/designs/9-automotive.stl
70.0 x 56.1 x 72.7

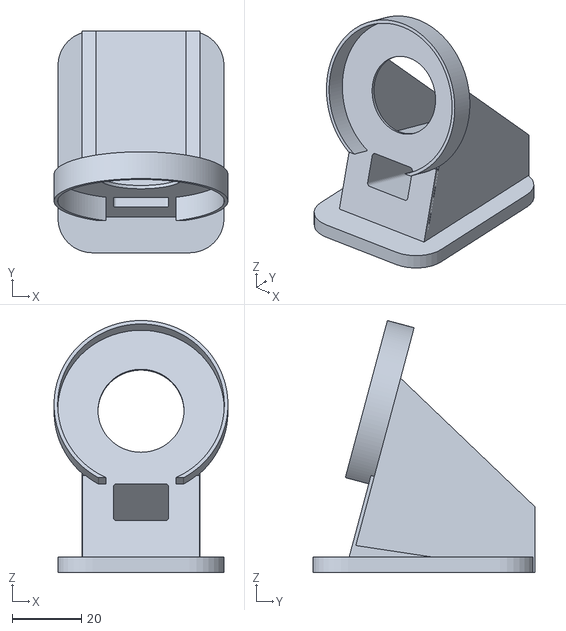
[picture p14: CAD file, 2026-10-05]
stand/designs/3-fin.stl
50.2 x 64.0 x 72.7

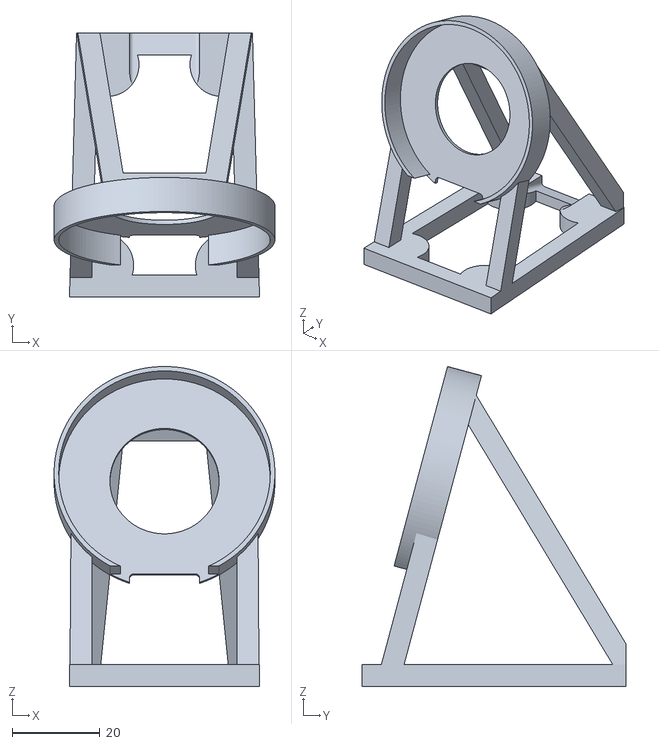
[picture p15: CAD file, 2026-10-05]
stand/designs/5-trestle.stl
50.2 x 60.0 x 72.7

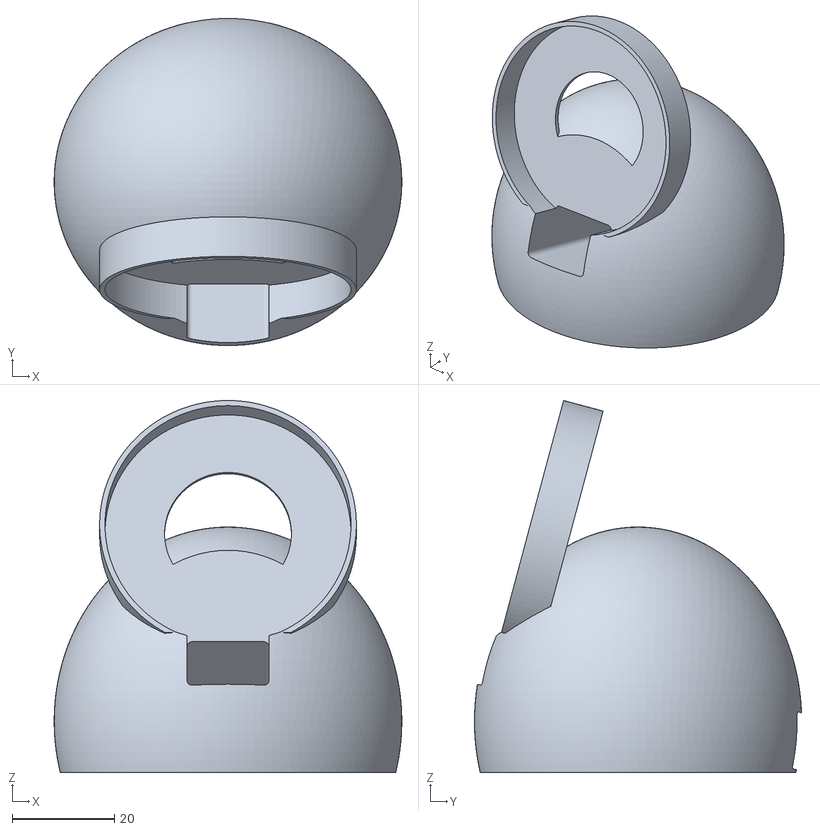
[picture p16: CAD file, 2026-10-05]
stand/designs/2-pebble.stl
68.0 x 64.0 x 72.7

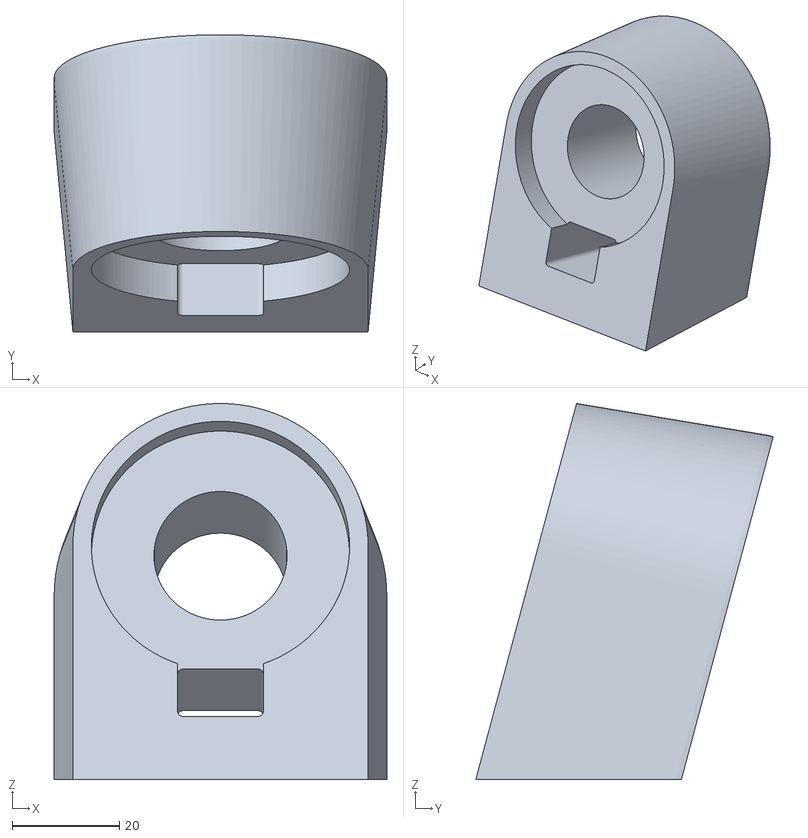
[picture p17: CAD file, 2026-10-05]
stand/designs/6-print.stl
62.0 x 55.4 x 70.1

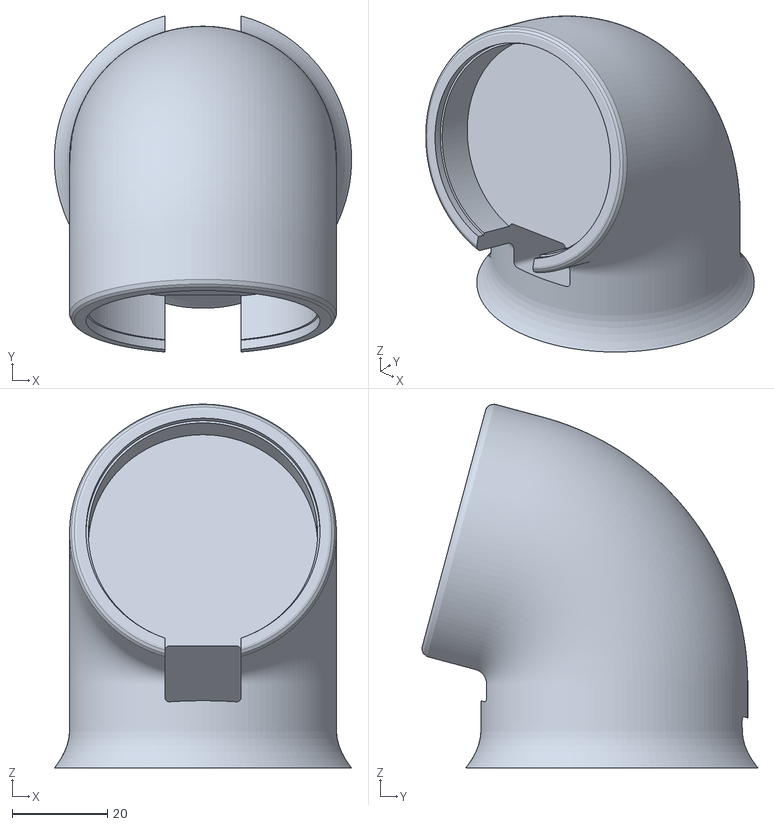
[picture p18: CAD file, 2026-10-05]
stand/designs/8-bend.stl
62.4 x 70.5 x 76.3

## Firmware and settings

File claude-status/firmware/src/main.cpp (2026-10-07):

// Claude Code status display for the Waveshare ESP32-S3-LCD-1.28.
//
// The Mac bridge (../bridge) POSTs a JSON summary to http://claude-status.local/state.
// When a session needs input the screen shows a full-screen alert; otherwise it shows
// session status, plan usage rings (5-hour outer, weekly inner) and today's activity, with a
// tabby cat acting out what's going on (see cat.cpp). The cat also walks across at power-on.
// Double-tapping the case dismisses the alert or Done card on screen, as does a short press of the
// BOOT button if your case leaves it reachable; tapping it five times quickly shows diagnostics
// (see taps.cpp). Holding BOOT for 5 seconds forgets the Wi-Fi network and reopens Wi-Fi setup.
// Without the button: power the display on 3 times in a row (each within 10 s of the last), or
// POST http://claude-status.local/wifi/reset.
//
// Wi-Fi setup: with no saved network, the display opens its own "Claude-Monitor-Setup"
// network. Join it from a phone (scan the QR code on screen) and pick your Wi-Fi.
// The timezone comes from the Mac helper, so there's nothing to configure in code.
//
// Updates: the Mac helper pairs with the display once (POST /pair with a random key) and
// can then send new firmware over Wi-Fi (POST /update with that key). Powering on 3 times
// in a row also clears the pairing, for when the Mac's key is lost.

#include <Arduino.h>
#include <ArduinoJson.h>
#include <ESPmDNS.h>
#include <LovyanGFX.hpp>
#include <Preferences.h>
#include <WebServer.h>
#include <WiFi.h>
#include <Update.h>
#include <WiFiManager.h>
#include <esp_system.h>
#include <esp_timer.h>
#include <time.h>

#include <vector>

#include "cat.h"
#include "taps.h"

#if __has_include("secrets.h") && !defined(RELEASE_BUILD)  // never in release images
#include "secrets.h"  // optional: pre-fills Wi-Fi for development builds (git-ignored)
#endif

constexpr const char *HOSTNAME = "claude-status";
#ifndef FW_VERSION
#define FW_VERSION "dev"  // set by tools/build-release.sh
#endif
constexpr const char *SETUP_AP = "Claude-Monitor-Setup";      // Wi-Fi setup network name
constexpr const char *DEFAULT_TZ = "UTC0";                    // until the Mac helper sends its timezone
constexpr uint32_t RESET_HOLD_MS = 5000;                      // hold BOOT this long to reset Wi-Fi
constexpr uint8_t RESET_POWER_CYCLES = 3;                     // ...or power it on this many times in a row
constexpr uint32_t POWER_CYCLE_WINDOW_MS = 10000;             // each within this long of the last
constexpr uint32_t STALE_MS = 30000;                          // no push for this long = Mac offline
constexpr float TAP_G = 0.25f;                                // how firm each tap on the case must be, in g
constexpr uint32_t DIAGNOSTICS_MS = 30000;                    // five quick taps show diagnostics this long

// ---- Board pins (Waveshare wiki, non-touch version) ----
constexpr int PIN_LCD_DC   = 8;
constexpr int PIN_LCD_CS   = 9;
constexpr int PIN_LCD_SCLK = 10;
constexpr int PIN_LCD_MOSI = 11;
constexpr int PIN_LCD_RST  = 12;
constexpr int PIN_LCD_BL   = 40;
constexpr int PIN_BOOT     = 0;

class LGFX : public lgfx::LGFX_Device {
  lgfx::Panel_GC9A01 _panel;
  lgfx::Bus_SPI _bus;
  lgfx::Light_PWM _light;

 public:
  LGFX() {
    {
      auto cfg = _bus.config();
      cfg.spi_host = SPI2_HOST;
      cfg.spi_mode = 0;
      cfg.freq_write = 40000000;
      cfg.freq_read = 16000000;
      cfg.spi_3wire = true;
      cfg.use_lock = true;
      cfg.dma_channel = SPI_DMA_CH_AUTO;
      cfg.pin_sclk = PIN_LCD_SCLK;
      cfg.pin_mosi = PIN_LCD_MOSI;
      cfg.pin_miso = -1;
      cfg.pin_dc = PIN_LCD_DC;
      _bus.config(cfg);
      _panel.setBus(&_bus);
    }
    {
      auto cfg = _panel.config();
      cfg.pin_cs = PIN_LCD_CS;
      cfg.pin_rst = PIN_LCD_RST;
      cfg.pin_busy = -1;
      cfg.panel_width = 240;
      cfg.panel_height = 240;
      cfg.readable = false;
      cfg.invert = true;
      cfg.rgb_order = false;
      cfg.bus_shared = false;
      _panel.config(cfg);
    }
    {
      auto cfg = _light.config();
      cfg.pin_bl = PIN_LCD_BL;
      cfg.invert = false;
      cfg.freq = 44100;
      cfg.pwm_channel = 7;
      _light.config(cfg);
      _panel.setLight(&_light);
    }
    setPanel(&_panel);
  }
};

static LGFX lcd;
static LGFX_Sprite frame(&lcd);
static WebServer server(80);

constexpr int CX = 120, CY = 120;

// Colours
const uint32_t COL_BG      = 0x0B0F1A;
const uint32_t COL_TRACK   = 0x1C2230;
const uint32_t COL_TEXT    = 0xF2F4F8;
const uint32_t COL_DIM     = 0xA6AEBF;
const uint32_t COL_FAINT   = 0x5A6478;
const uint32_t COL_CLAUDE  = 0xD97757;
const uint32_t COL_BRIGHT  = 0xFF9B73;
const uint32_t COL_WEEK    = 0x6A9BCC;
const uint32_t COL_OK      = 0x34C759;
const uint32_t COL_WARN    = 0xFFD60A;
const uint32_t COL_ERR     = 0xFF453A;

// ---- State pushed from the Mac ----

struct Session {
  String id, name, state, kind, detail;
  uint32_t since = 0;
};

// CI checks on the pull request for the session open in the Claude app
struct CI {
  bool present = false;
  String id;           // that session's id
  String title;        // "#1252 Fix the thing"
  String status;       // "running", "passed", "failed" or "cancelled"
  String checks;       // a letter per check, in ring order: P passed, F failed, C cancelled, R running, Q queued
  String detail;       // the checks that failed, or that are running
  String key;          // changes when there's something new to show
  uint32_t since = 0;  // when the run started (while running) or finished
};

struct State {
  bool valid = false;
  uint32_t rxMillis = 0;
  std::vector<Session> sessions;
  int busy = 0, idle = 0, waiting = 0, done = 0, errors = 0;
  bool haveUsage = false;
  float h5 = -1, d7 = -1;
  uint32_t h5Reset = 0, d7Reset = 0;
  bool haveToday = false;
  double tokens = 0;
  uint32_t prompts = 0;
  String update;    // newer release available, e.g. "v1.1.0"
  String incident;  // an Anthropic incident affecting Claude Code, from status.claude.com
  CI ci;
};

static State st;
static String dismissedWaiting, dismissedDone;  // sessions on screen when you last dismissed each card
static String dismissedCI;                      // the CI card's key when you last dismissed it
static bool tapReady = false;                   // the motion sensor was found, so taps on the case work
static WiFiManager wifiManager;
static Preferences prefs;
static String currentTz;
static uint8_t powerCycles = 0;  // consecutive quick power-ons, for the no-button Wi-Fi reset
static String pairKey;           // shared with the Mac helper; required for firmware updates
static bool showCat = true;      // the cat and its power-on walk ("cat" in the helper's config.json)

static void applyTimezone(const String &tz) {
  currentTz = tz;
  setenv("TZ", tz.c_str(), 1);
  tzset();
}

static void handleState() {
  JsonDocument doc;
  if (deserializeJson(doc, server.arg("plain"))) {
    server.send(400, "text/plain", "bad json");
    return;
  }
  State s;
  s.valid = true;
  s.rxMillis = millis();
  for (JsonObject o : doc["sessions"].as<JsonArray>()) {
    Session x;
    x.id = (const char *)(o["id"] | "");
    x.name = (const char *)(o["name"] | "");
    x.state = (const char *)(o["state"] | "idle");
    x.kind = (const char *)(o["kind"] | "");
    x.detail = (const char *)(o["detail"] | "");
    x.since = o["since"] | 0;
    s.sessions.push_back(x);
  }
  JsonObject c = doc["counts"];
  s.busy = c["busy"] | 0;
  s.idle = c["idle"] | 0;
  s.waiting = c["waiting"] | 0;
  s.done = c["done"] | 0;
  s.errors = c["error"] | 0;
  JsonObject u = doc["usage"];
  if (!u.isNull()) {
    s.haveUsage = true;
    s.h5 = u["h5"] | -1.0f;
    s.d7 = u["d7"] | -1.0f;
    s.h5Reset = u["h5_reset"] | 0;
    s.d7Reset = u["d7_reset"] | 0;
  }
  JsonObject t = doc["today"];
  if (!t.isNull()) {
    s.haveToday = true;
    s.tokens = t["tokens"] | 0.0;
    s.prompts = t["prompts"] | 0;
  }
  JsonObject ci = doc["ci"];
  if (!ci.isNull() && strlen(ci["checks"] | "")) {
    s.ci.present = true;
    s.ci.id = (const char *)(ci["id"] | "");
    s.ci.title = (const char *)(ci["title"] | "");
    s.ci.status = (const char *)(ci["status"] | "");
    s.ci.checks = (const char *)(ci["checks"] | "");
    s.ci.detail = (const char *)(ci["detail"] | "");
    s.ci.key = (const char *)(ci["key"] | "");
    s.ci.since = ci["since"] | 0;
  }
  s.update = (const char *)(doc["update"] | "");
  if (!doc["incident"].isNull()) s.incident = (const char *)(doc["incident"]["name"] | "Claude incident");
  st = std::move(s);

  // The Mac helper sends its timezone as a POSIX TZ string; remember it across reboots
  String tz = (const char *)(doc["tz"] | "");
  if (tz.length() && tz != currentTz) {
    applyTimezone(tz);
    prefs.putString("tz", tz);
    Serial.println("Timezone set to " + tz);
  }

  // Remembered too, so the power-on walk follows it before the Mac is heard from
  bool cat = doc["cat"] | true;
  if (cat != showCat) {
    showCat = cat;
    prefs.putBool("cat", cat);
  }
  server.send(200, "application/json", "{\"ok\":true}");
}

static void handleWifiReset() {
  server.send(200, "text/plain", "Forgetting Wi-Fi and restarting into Wi-Fi setup\n");
  delay(300);
  wifiManager.resetSettings();
  ESP.restart();
}

static void handleRoot() {
  String out = "claude-status display " FW_VERSION "\nIP " + WiFi.localIP().toString() + "\nlast push " +
               (st.valid ? String((millis() - st.rxMillis) / 1000) + "s ago" : String("never")) + "\n" +
               (tapReady ? "taps seen: " + String(doubleTapCount()) + " double, " + String(fiveTapCount()) + " five"
                         : String("no motion sensor: taps on the case don't work")) + "\n";
  server.send(200, "text/plain", out);
}

// Streams the last rendered frame as a 24-bit BMP (handy for checking layouts remotely).
static void handleScreenshot() {
  const int W = 240, H = 240, rowBytes = W * 3, size = 54 + rowBytes * H;
  uint8_t hdr[54] = {'B', 'M'};
  auto put32 = [&](int off, uint32_t v) { memcpy(hdr + off, &v, 4); };
  put32(2, size);
  put32(10, 54);
  put32(14, 40);
  put32(18, W);
  put32(22, H);
  hdr[26] = 1;
  hdr[28] = 24;
  put32(34, rowBytes * H);
  WiFiClient client = server.client();
  server.setContentLength(size);
  server.send(200, "image/bmp", "");
  client.write(hdr, sizeof(hdr));
  static uint8_t row[W * 3];
  for (int y = H - 1; y >= 0; y--) {  // BMP rows are bottom-up, BGR
    for (int x = 0; x < W; x++) {
      auto c = frame.readPixelRGB(x, y);
      row[x * 3] = c.B8();
      row[x * 3 + 1] = c.G8();
      row[x * 3 + 2] = c.R8();
    }
    client.write(row, rowBytes);
  }
}

// ---- Drawing helpers ----

static uint32_t lerpColor(uint32_t a, uint32_t b, float t) {
  auto ch = [&](int shift) {
    int x = (a >> shift) & 0xFF, y = (b >> shift) & 0xFF;
    return (uint32_t)(x + (y - x) * t) & 0xFF;
  };
  return ch(16) << 16 | ch(8) << 8 | ch(0);
}

static uint32_t usageColor(float pct, uint32_t base) {
  if (pct >= 90) return COL_ERR;
  if (pct >= 75) return COL_WARN;
  return base;
}

// Usable width for a line of text centred at height y, inside a circle of radius r
// (the inner edge of a ring, minus a margin). h is about half the font's height.
static int chordWidth(int y, int r, int h = 8) {
  int dy = abs(y - CY) + h;
  return dy >= r ? 0 : (int)(2 * sqrtf((float)(r * r - dy * dy)));
}

constexpr int CARD_TEXT_R = 100;    // alert / Done cards: ring inner edge 106
constexpr int STATUS_TEXT_R = 90;   // status screen: inner usage ring's inner edge 96

static String fit(const String &s, int maxW);

// The first wording that fits (set the font first); the last one is truncated if none do.
static String firstFit(std::initializer_list<String> options, int maxW) {
  String last;
  for (const String &o : options) {
    if (frame.textWidth(o) <= maxW) return o;
    last = o;
  }
  return fit(last, maxW);
}

static String fit(const String &s, int maxW) {
  if (frame.textWidth(s) <= maxW) return s;
  String t = s;
  while (t.length() > 1 && frame.textWidth(t + "..") > maxW) t.remove(t.length() - 1);
  t.trim();
  return t + "..";
}

// Greedy word wrap into at most two lines; the second is truncated.
static void wrap2(const String &s, int maxW, String &l1, String &l2) {
  l2 = "";
  if (frame.textWidth(s) <= maxW) {
    l1 = s;
    return;
  }
  int cut = -1;
  for (int i = 1; i < (int)s.length(); i++)
    if (s[i] == ' ' && frame.textWidth(s.substring(0, i)) <= maxW) cut = i;
  if (cut < 0) {
    l1 = fit(s, maxW);
    return;
  }
  l1 = s.substring(0, cut);
  l2 = fit(s.substring(cut + 1), maxW);
}

static String duration(int32_t s) {
  if (s <= 0) return "now";
  if (s < 60) return String(s) + "s";
  if (s < 3600) return String(s / 60) + "m";
  if (s < 86400) return String(s / 3600) + "h" + String((s % 3600) / 60) + "m";
  return String(s / 86400) + "d" + String((s % 86400) / 3600) + "h";
}

static String compact(double v) {
  char b[16];
  if (v >= 1e9) snprintf(b, sizeof(b), "%.1fB", v / 1e9);
  else if (v >= 1e6) snprintf(b, sizeof(b), "%.1fM", v / 1e6);
  else if (v >= 1e3) snprintf(b, sizeof(b), "%.0fk", v / 1e3);
  else snprintf(b, sizeof(b), "%.0f", v);
  return b;
}

// Progress ring starting at 12 o'clock, clockwise, with rounded ends.
static void ring(int r0, int r1, float pct, uint32_t col) {
  frame.fillArc(CX, CY, r0, r1, 0, 360, COL_TRACK);
  if (pct <= 0) return;
  pct = min(pct, 100.0f);
  float end = -90 + 3.6f * pct;
  frame.fillArc(CX, CY, r0, r1, -90, end, col);
  float rm = (r0 + r1) / 2.0f, rw = (r1 - r0) / 2.0f;
  float a = end * DEG_TO_RAD;
  frame.fillSmoothCircle(CX, CY - rm, rw, col);
  frame.fillSmoothCircle(CX + rm * cosf(a), CY + rm * sinf(a), rw, col);
}

static void text(const String &s, int x, int y, uint32_t col, const lgfx::IFont *font,
                 textdatum_t datum = textdatum_t::middle_center) {
  frame.setFont(font);
  frame.setTextDatum(datum);
  frame.setTextColor(col);
  frame.drawString(s, x, y);
}

static float pulse(float periodMs) { return 0.5f + 0.5f * sinf(millis() * TWO_PI / periodMs); }

// A line of Font2 text centred at height y; if it's wider than w, it scrolls sideways through
// that width like a ticker, so all of it can be read
static void ticker(const String &s, int y, int w, uint32_t col) {
  frame.setFont(&fonts::Font2);
  int tw = frame.textWidth(s);
  if (tw <= w) {
    text(s, CX, y, col, &fonts::Font2);
    return;
  }
  const int gap = 48, x0 = CX - w / 2;
  int off = (millis() / 30) % (tw + gap);  // ~33 px a second
  frame.setClipRect(x0, y - 9, w, 18);
  text(s, x0 - off, y, col, &fonts::Font2, textdatum_t::middle_left);
  text(s, x0 - off + tw + gap, y, col, &fonts::Font2, textdatum_t::middle_left);
  frame.clearClipRect();
}

// ---- Screens ----

static const char *headline(const String &kind) {
  if (kind == "permission") return "Permission";
  if (kind == "question") return "Question";
  if (kind == "plan") return "Plan ready";
  return "Needs input";
}

// "waiting 3m  +1 more" at the bottom of a card, shortened to fit the narrow bottom of the circle
static void drawCardFooter(const char *before, const char *after, uint32_t since, int others) {
  const int y = 190;
  time_t now = time(nullptr);
  String t = since && now > 1700000000 ? duration(now - since) : String("");
  String more = others > 0 ? "+" + String(others) + " more" : String("");
  String sep = t.length() && more.length() ? "  " : "";
  String full = t.length() ? before + t + after : String("");
  String brief = t.length() ? t + after : String("");
  frame.setFont(&fonts::Font2);
  String foot = firstFit({full + sep + more, brief + sep + more,
                          brief + sep + (others > 0 ? "+" + String(others) : String("")), brief},
                         chordWidth(y, CARD_TEXT_R));
  text(foot, CX, y, COL_FAINT, &fonts::Font2);
}

static void drawAlert(const Session &s, int others) {
  frame.fillScreen(COL_BG);
  float p = pulse(1600);
  frame.fillArc(CX, CY, 106, 120, 0, 360, lerpColor(0x5A2414, COL_BRIGHT, p));

  frame.fillSmoothCircle(CX, 56, 19, COL_CLAUDE);
  text(s.kind == "question" ? "?" : "!", CX, 57, COL_BG, &fonts::FreeSansBold12pt7b);

  text(headline(s.kind), CX, 96, COL_TEXT, &fonts::FreeSansBold12pt7b);

  frame.setFont(&fonts::FreeSans9pt7b);
  String l1, l2;
  wrap2(s.name, 176, l1, l2);
  text(l1, CX, 124, COL_DIM, &fonts::FreeSans9pt7b);
  if (l2.length()) text(l2, CX, 144, COL_DIM, &fonts::FreeSans9pt7b);

  // Detail (e.g. the question): two lines when the session name fits on one
  frame.setFont(&fonts::Font2);
  if (l2.length()) {
    text(fit(s.detail, 150), CX, 168, COL_BRIGHT, &fonts::Font2);
  } else {
    String d1, d2;
    wrap2(s.detail, 160, d1, d2);
    text(d1, CX, d2.length() ? 152 : 158, COL_BRIGHT, &fonts::Font2);
    if (d2.length()) text(d2, CX, 168, COL_BRIGHT, &fonts::Font2);
  }

  drawCardFooter("waiting ", "", s.since, others);
}

// Green card for a session that finished; stays until you reply to it.
static void drawDone(const Session &s, int others) {
  frame.fillScreen(COL_BG);
  frame.fillArc(CX, CY, 106, 120, 0, 360, lerpColor(0x0F3D1E, COL_OK, 0.55f + 0.45f * pulse(4000)));

  frame.fillSmoothCircle(CX, 56, 19, COL_OK);
  frame.drawWedgeLine(CX - 9, 57, CX - 3, 63, 2.5, 2.5, COL_BG);  // check mark
  frame.drawWedgeLine(CX - 3, 63, CX + 9, 50, 2.5, 2.5, COL_BG);

  text("Done", CX, 96, COL_TEXT, &fonts::FreeSansBold12pt7b);

  frame.setFont(&fonts::FreeSans9pt7b);
  String l1, l2;
  wrap2(s.name, 176, l1, l2);
  text(l1, CX, 124, COL_DIM, &fonts::FreeSans9pt7b);
  if (l2.length()) text(l2, CX, 144, COL_DIM, &fonts::FreeSans9pt7b);

  // What it got done, when the helper's reply check provides a summary
  const uint32_t COL_DONE_TEXT = 0x7EE2A0;
  frame.setFont(&fonts::Font2);
  if (l2.length()) {
    text(fit(s.detail, 150), CX, 168, COL_DONE_TEXT, &fonts::Font2);
  } else {
    String d1, d2;
    wrap2(s.detail, 160, d1, d2);
    text(d1, CX, d2.length() ? 152 : 158, COL_DONE_TEXT, &fonts::Font2);
    if (d2.length()) text(d2, CX, 168, COL_DONE_TEXT, &fonts::Font2);
  }

  drawCardFooter("finished ", " ago", s.since, others);
}
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
void loop() {
  static bool serverStarted = false, wasConnected = false;
  bool connected = WiFi.status() == WL_CONNECTED;
  updatePowerCycleWindow();

  if (wifiManager.getConfigPortalActive()) {
    wifiManager.process();
    if (!connected) {
      if (!handleBootButton()) {
        drawWifiSetup();
        frame.pushSprite(0, 0);
      }
      delay(15);
      return;
    }
    wifiManager.stopConfigPortal();  // joined a network: close the setup network
  }

  if (connected && !wasConnected) {
    Serial.println("Wi-Fi connected, IP " + WiFi.localIP().toString());
    if (!serverStarted) {  // the setup portal uses port 80 too, so start ours once it's closed
      server.begin();
      if (MDNS.begin(HOSTNAME)) MDNS.addService("http", "tcp", 80);
      Serial.printf("mDNS: %s.local\n", HOSTNAME);
      serverStarted = true;
    }
  }
  wasConnected = connected;

  if (serverStarted) server.handleClient();

  bool pressed = false;
  if (handleBootButton(&pressed)) {
    delay(15);
    return;
  }

  // Taps on the case: five quick taps open diagnostics, and a double tap (like a BOOT press)
  // closes them, or otherwise dismisses the card on screen
  static uint32_t doubles = 0, fives = 0, diagnosticsSince = 0;
  uint32_t d = doubleTapCount(), f = fiveTapCount();
  bool dismiss = pressed || d != doubles;
  if (f != fives) {
    diagnosticsSince = millis() | 1;
  } else if (diagnosticsSince && (dismiss || millis() - diagnosticsSince > DIAGNOSTICS_MS)) {
    diagnosticsSince = 0;
    dismiss = false;  // closing diagnostics doesn't also dismiss the card underneath
  }
  doubles = d;
  fives = f;

  bool stale = st.valid && millis() - st.rxMillis > STALE_MS;
  Pick card = pickCard(stale);
  if (dismiss && !diagnosticsSince) {
    if (card.alert) dismissedWaiting = stateKey("waiting");
    else if (card.ci) dismissedCI = st.ci.key;
    else if (card.done) dismissedDone = stateKey("done");
    card = pickCard(stale);
  }

  if (diagnosticsSince) drawDiagnostics(millis() - diagnosticsSince);
  else if (card.alert) drawAlert(*card.alert, card.waiting - 1);
  else if (card.ci) drawCI(st.ci);
  else if (card.done) drawDone(*card.done, st.done - 1);
  else drawStatus(stale);
  frame.pushSprite(0, 0);

  static int brightness = -1;
  int want = card.alert && !diagnosticsSince ? 255 : 150;
  if (want != brightness) lcd.setBrightness(brightness = want);

  delay(15);
}

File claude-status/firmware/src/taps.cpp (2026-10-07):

// Taps on the display's case, detected with the board's QMI8658 motion sensor.
//
// A task on core 0 reads the accelerometer 1000 times a second and measures the jolt: how far
// each reading is from the slowly changing direction of gravity. A hit starts when the jolt jumps
// well above the fading echo of earlier hits, and is judged 200 ms later: it's a tap if it was
// strong enough and the display didn't tilt (it wasn't being picked up or moved).
//
// Taps 80-450 ms apart make a run. A run of exactly two is a double tap, counted once the run is
// over (so it isn't the start of five taps); the fifth tap of a run counts as five taps straight away.
//
// Measured on a display in a desk stand: taps on the case 0.26-1.7 g; putting a mug down or
// knocking on the desk 0.10-0.19 g; typing on the same desk doesn't register at all; picking the
// display up builds up too gradually to start a hit.

#include "taps.h"

#include <Arduino.h>
#include <Wire.h>

#include <algorithm>

namespace {

constexpr int PIN_SDA = 6, PIN_SCL = 7;
constexpr uint8_t REG_WHO_AM_I = 0x00, REG_CTRL1 = 0x02, REG_CTRL2 = 0x03, REG_CTRL5 = 0x06,
                  REG_CTRL7 = 0x08, REG_AX_L = 0x35, REG_RST_RESULT = 0x4D, REG_RESET = 0x60;
constexpr float COUNTS_PER_G = 4096;  // +-8 g range

// Times are in samples, about 1 ms each
constexpr float HIT_G = 0.05f;           // smallest jolt that can start a hit
constexpr float ONSET_RATIO = 2.5f;      // ...and it must jump this far above the echo of earlier hits
constexpr float ECHO_DECAY = 0.975f;     // per sample: the echo fades over ~40 ms
constexpr float GRAVITY_FOLLOW = 0.01f;  // per sample: gravity follows slow changes over ~100 ms
constexpr uint32_t LOCKOUT = 40;         // a hit's own ringing can't start another hit
constexpr uint32_t SETTLE = 200;         // judge a hit this long after it starts
constexpr float MAX_TILT_DEG = 10;       // tilted more than this: moved, not tapped
constexpr uint32_t GAP_MIN = 80;         // a tap closer than this to the last one is the case rattling
constexpr uint32_t GAP_MAX = 450;        // taps further apart than this start a new run
constexpr uint32_t NONE = UINT32_MAX;
constexpr int RING = 1024;
constexpr int MAX_PENDING = 8;

uint8_t addr = 0;
float minTapG = 0.25f;
volatile uint32_t doubles = 0, fives = 0;
int16_t recent[RING][3];  // recent readings, for measuring tilt around a hit

bool writeReg(uint8_t reg, uint8_t val) {
  Wire.beginTransmission(addr);
  Wire.write(reg);
  Wire.write(val);
  return Wire.endTransmission() == 0;
}

bool readRegs(uint8_t reg, uint8_t *buf, uint8_t n) {
  Wire.beginTransmission(addr);
  Wire.write(reg);
  if (Wire.endTransmission(false) != 0 || Wire.requestFrom(addr, n) != n) return false;
  for (uint8_t i = 0; i < n; i++) buf[i] = Wire.read();
  return true;
}

int16_t median3(int16_t a, int16_t b, int16_t c) { return std::max(std::min(a, b), std::min(std::max(a, b), c)); }

// Direction of gravity over samples [from, to): the median on each axis, so a tap inside doesn't skew it
void gravity(uint32_t from, uint32_t to, float g[3]) {
  int16_t v[100];
  const int n = to - from;
  for (int k = 0; k < 3; k++) {
    for (int i = 0; i < n; i++) v[i] = recent[(from + i) % RING][k];
    std::nth_element(v, v + n / 2, v + n);
    g[k] = v[n / 2];
  }
}

// How far the display tilted between just before a hit and just after it, in degrees
float tiltDeg(uint32_t hit) {
  float a[3], b[3];
  gravity(hit - 200, hit - 100, a);
  gravity(hit + 100, hit + 200, b);
  float dot = a[0] * b[0] + a[1] * b[1] + a[2] * b[2];
  float na = sqrtf(a[0] * a[0] + a[1] * a[1] + a[2] * a[2]);
  float nb = sqrtf(b[0] * b[0] + b[1] * b[1] + b[2] * b[2]);
  if (na == 0 || nb == 0) return 0;
  return acosf(constrain(dot / (na * nb), -1.0f, 1.0f)) * RAD_TO_DEG;
}

void watch(void *) {
  int16_t older[3] = {}, old[3] = {};
  float base[3] = {}, echo = 0;
  uint32_t reads = 0, n = 0;
  uint32_t hitAt[MAX_PENDING];  // hits waiting to be judged, oldest first
  float hitPeak[MAX_PENDING];
  int hits = 0;
  uint32_t lastTap = NONE;  // when the latest tap of the current run started
  int run = 0;              // taps in the current run
  TickType_t wake = xTaskGetTickCount();
  for (;;) {
    vTaskDelayUntil(&wake, 1);
    uint8_t b[6];
    if (!readRegs(REG_AX_L, b, 6)) continue;

    // The sensor updates faster than we read it, so now and then a value's low and high bytes
    // come from different samples: a one-sample spike of 256 counts. A median of three removes
    // those; real movement lasts several samples.
    int16_t s[3];
    for (int k = 0; k < 3; k++) {
      int16_t cur = (int16_t)(b[2 * k] | b[2 * k + 1] << 8);
      s[k] = median3(older[k], old[k], cur);
      older[k] = old[k];
      old[k] = cur;
    }
    if (++reads < 3) continue;

    float jolt2 = 0;
    for (int k = 0; k < 3; k++) {
      float a = s[k] / COUNTS_PER_G;
      if (n == 0) base[k] = a;
      float d = a - base[k];
      base[k] += GRAVITY_FOLLOW * d;
      jolt2 += d * d;
    }
    float jolt = sqrtf(jolt2), echoBefore = echo;
    echo = std::max(jolt, echo * ECHO_DECAY);
    uint32_t i = n++;
    memcpy(recent[i % RING], s, sizeof(s));
    if (i < 500) continue;  // let gravity settle after power-on

    if ((hits == 0 || i - hitAt[hits - 1] >= LOCKOUT) && hits < MAX_PENDING && jolt >= HIT_G &&
        jolt >= ONSET_RATIO * echoBefore) {
      hitAt[hits] = i;
      hitPeak[hits++] = jolt;
    }
    for (int h = 0; h < hits; h++)
      if (i - hitAt[h] < LOCKOUT) hitPeak[h] = std::max(hitPeak[h], jolt);

    if (hits && i - hitAt[0] >= SETTLE) {
      uint32_t at = hitAt[0];
      float peak = hitPeak[0];
      hits--;
      for (int h = 0; h < hits; h++) {
        hitAt[h] = hitAt[h + 1];
        hitPeak[h] = hitPeak[h + 1];
      }
      uint32_t gap = lastTap == NONE ? NONE : at - lastTap;
      if (peak >= minTapG && gap >= GAP_MIN && tiltDeg(at) <= MAX_TILT_DEG) {
        run = gap <= GAP_MAX ? run + 1 : 1;
        lastTap = at;
        if (run == 5) fives++;
      }
    }

    // The run is over once no more taps can join it (any hit still being judged started too late)
    if (run && i - lastTap > GAP_MAX && (hits == 0 || hitAt[0] - lastTap > GAP_MAX)) {
      if (run == 2) doubles++;
      run = 0;
    }
  }
}

}  // namespace
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

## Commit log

2026-10-05 Claude Monitor: a round desk display for Claude Code
    A Waveshare ESP32-S3 round display that shows what Claude Code is doing
    and lights up when Claude needs you: permission prompts, questions and
    plan approvals in Claude Code, plus tool approvals and questions in
    Claude app chats. Also shows plan usage and today's activity.
    - claude-status/firmware: ESP32-S3 firmware (phone Wi-Fi setup, status
    and alert screens)
    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
    [1-halo.stl, 2-pebble.stl, 3-fin.stl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]
2026-10-05 Update the setup skill for the public repo
    - Flash the published firmware from the installer site with esptool by
    default (no build, keeps saved Wi-Fi); building from source is option B.
    - Install the helper into ~/Library/Application Support/Claude Monitor,
    the same place as Install.command, so a deleted download doesn't break it.
    - Add public links, an Updating section and maintainer notes; drop the
    outdated Python-path and BOOT-button advice.
    - README Option 1 now says Claude flashes the published firmware.
2026-10-06 Catch any reply that's waiting on you, not just questions
    - Broader phrase matching for the end of a Claude Code turn: approval and
    confirmation requests ("after you approve", "please confirm"), offers
    ("should I", "would you like") and hand-offs ("over to you").
    - When the phrases don't match, the helper asks Claude Haiku through the
    isolated `claude` CLI whether the reply is waiting on the user, and shows
    its one-line summary. The reply is wrapped in <message> tags so it's
    treated as data. Off with "check_replies": false; skipped for 30 minutes
    if the CLI isn't signed in.
    - The check runs off the hook thread and is discarded if a new prompt
    arrives first. On startup, idle ses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
2026-10-06 Add updates: one command, Wi-Fi firmware updates, notice and skill
    - Firmware: GET /info (version, paired), POST /pair (first Mac to pair
    owns the display; 3 quick power-ons reset it) and POST /update, which
    writes a new app image to the spare slot and restarts into it. Needs the
    pairing key. Shows a progress ring while updating, and alternates the
    footer with "Update: vX" when the helper reports a newer release.
    - Helper: pairs with the display automatically (random key in
    config.json), checks GitHub for the latest release once a day and
    tells the display. New update.py / update.sh update the helper from the
    release zip (keeping config.json) and the display over Wi-Fi.
    - Insta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
    [main.cpp]
2026-10-07 Add LilyGO T-RGB support
    New lilygo-t-rgb PlatformIO environment. The 240x240 UI is scaled up 2x
    with smoothing onto the T-RGB's 480x480 ST7701S RGB panel, driven by
    LilyGO's MIT-licensed panel driver (vendored in src/trgb), which detects
    the 2.1" and 2.8" variants. Wi-Fi updates on a T-RGB only accept images
    built for it, so release (Waveshare) firmware can't be pushed to it.
    Claude-Session: https://claude.ai/code/session_01Fu7jWGxnYRKhnsLw9M6web
2026-10-07 Keep text inside the rings on the round screen
    Lines near the bottom of the circle were limited to a fixed width, so long
    footers ("finished 3m ago +1 more") ran into the ring. Each line now uses
    the width actually available at its height (chordWidth), and footers fall
    back to shorter wordings before truncating: card footers drop "waiting" /
    "finished", the status screen's today line drops "prompts"/"tok", and the
    session list trims names on the lower rows.
    [main.cpp]
2026-10-07 Note that 2.1" V2 T-RGB boards need the panel type set
    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
2026-10-07 Add tap gestures, pace ticks, session timers and a CI card
    Display:
    - Double-tap the case to dismiss the alert, CI card or Done card, using
    the board's QMI8658 motion sensor (taps.cpp). Taps form runs: exactly
    two is a double tap; five open a diagnostics screen (firmware, Wi-Fi
    and signal, IP, name, when the Mac last updated it, uptime) that
    closes after 30 s. Tuned on a real desk: taps on the case measure
    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
2026-10-07 T-RGB: tap gestures from the touch screen
    Upstream's tap gestures read the Waveshare's QMI8658 motion sensor on
    GPIO 6/7, which are LCD data lines on the T-RGB. The T-RGB build leaves
    taps.cpp out and implements taps.h with the CST820/FT3267 touch screen:
    double-tap the screen to dismiss, five taps for diagnostics.
    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
2026-10-07 Show Anthropic incidents on the display instead of plan usage
    When Anthropic's status page reports an incident affecting Claude Code,
    the Claude API or claude.ai, the status screen swaps plan usage for a
    pulsing red ring, "Anthropic incident" and the incident's name (scrolling
    when it's too long to fit), so red error dots can be read as Anthropic's
    problem rather than yours.
    - The Mac helper checks status.claude.com's public summary every 2
    minutes in the background (IncidentWatcher). Only unresolved incidents
    linked to those components count, so a Console-only incident, like the
    one active while this was built, leaves the display alone. Minor
    incidents count too: most are elevated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
    [main.cpp]
2026-10-07 Add a tabby cat to the status screen, walking on at power-on
    A pixel-art brown tabby sits beside the status headline and acts it
    out: typing while sessions work (faster the more there are), waving
    when something still needs you after you've hidden its alert, cheering
    when sessions have finished, seeing stars after an API error, and
    curled up asleep when everything's idle or the Mac is offline. It's
    modelled on a real cat: a grey-brown mackerel tabby with a white
    muzzle, chest and paws, green eyes and a pink nose.
    - At power-on, a bigger side view of the cat walks across the empty
    screen (about 3.7 s) before anything else appears. It's skipped on
    the second and third quick replugs of the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
    [main.cpp]
2026-10-09 Keep the display reachable after Wi-Fi drops
    The Mac lost the display overnight: pushes timed out, then
    claude-status.local stopped resolving. Turn off Wi-Fi power saving,
    restart mDNS after every reconnect, and nudge Wi-Fi to reconnect if
    it's been down for a minute.
    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
2026-10-12 Add a menu bar app, night mode and a one-line installer
    A Claude Monitor icon in the Mac's menu bar now holds the options:
    connect plan usage with one click, set up night mode, and switch the
    cat, CI checks, incidents, chat alerts and the Haiku reply check on or
    off. New users can set everything up with one line in Terminal, which
    also puts the software on a display plugged in over USB.
    - The menu bar app (claude-status/menubar) is SwiftUI built with
    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
2026-10-13 Show the CI card and Wi-Fi setup screen at the top of the README
    The screenshots at the top of the README now run two rows of three.
    The two new ones are the CI card with checks still running, and the
    Wi-Fi setup screen with the QR code you scan from your phone.
    - The CI card is the existing screenshot: the card hasn't changed
    since it was taken.
    - The Wi-Fi setup screen was captured off the device with a temporary
    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
2026-10-13 Dismiss the card on the display from the menu bar app
    The menu bar panel now shows the card on the display's screen (a
    needs-input alert, a Done card or CI checks) with a Dismiss button
    that hides it just like a double tap on the case.
    - Firmware: the reply to POST /state says which card is on screen
    (key, icon, title, name, or null). A new POST /dismiss dismisses it
    with the double tap's code, but only if the key still matches, so a
    card that changed since the Mac last heard isn't hidden by mistake.
    - Helper: keeps the card from those replies and relays the panel's
    click with POST /display/dismiss. Failures answer 502 with a message
    (an older display, or one that can't be reached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
2026-10-13 Build both boards in CI; keep plain `pio run` on the Waveshare
    With two environments, a bare `pio run -t upload` would build and flash
    both onto whatever board is plugged in, so default_envs keeps it on the
    Waveshare as before. CI also builds the T-RGB environment as a check.
    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
2026-10-13 Release for both boards: T-RGB firmware, board-aware updates and installers
    - tools/build-release.sh builds every board: the Waveshare's files keep
    their names, the T-RGB's add -lilygo-t-rgb (app and full image), with
    installer parts in web/lilygo-t-rgb/ and manifest-lilygo-t-rgb.json.
    It checks each image carries its board tag. The release attaches both.
    - Both boards report their board in /info and only take Wi-Fi updates
    tagged for them (the Waveshare too now), with an exact (KMP) scan.
    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
2026-10-13 Support the Waveshare ESP32-S3-Touch-LCD-1.28
    The touch version of the board moves the LCD reset pin from GPIO 12 to 14
    and the backlight from GPIO 40 to 2. With the stock firmware it boots and
    opens Wi-Fi setup, but the screen stays black.
    Add a waveshare-s3-touch-lcd128 PlatformIO environment that builds with
    BOARD_WAVESHARE_TOUCH, which swaps those two pins and reports its own board
    name in /info. Touch builds carry an OTA board tag and refuse Wi-Fi updates
    without it, so an update with the non-touch image can't black out the
    screen. The default build, releases and installer are unchanged.
    Claude-Session: https://claude.ai/code/ses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
2026-10-14 Jump to a card's session: tap on the T-RGB, Open in the menu bar app
    A single tap on an alert, Done or CI card on a touch screen (the T-RGB)
    asks the Mac to bring up the app that session runs in; the menu bar app
    gets an Open button next to Dismiss that does the same on any board.
    - Firmware: the card in replies carries its session id, and replies
    carry an open request {boot, seq, id, tap}. A single tap (T-RGB touch
    taps now count runs of one) bumps seq and shows 'Opening on your Mac'.
    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
2026-10-14 Open: skip Claude Code's own app bundle
    Tested on a Mac: a VS Code session 'opened in claude', because the
    claude CLI there runs from a bundle of its own (claude.app), which was
    the nearest .app. Start from the session's parent and skip claude.app,
    so the walk reaches VS Code (or Terminal, or the Claude app). The log
    names the bundle opened, and the process chain when none is found.
    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
2026-10-15 Swipe between Macs on the touch display
    On the Waveshare touch board, the CST816S touch controller is now read
    for swipes, from the motion sensor's task since both share the I2C bus.
    Once two or more Macs have pushed, swiping the status screen moves
    between all Macs and a page for each Mac: its name, its own sessions and
    activity, or Offline with when it was last seen. Dots show the page.
    Alerts and Done cards still come from every Mac whatever the page, and
    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
2026-10-15 Talk to the display over USB when Wi-Fi can't reach it
    The helper falls back to the display's USB cable whenever a push over
    Wi-Fi fails, and checks once a minute whether Wi-Fi works again. The
    firmware accepts the same requests as line commands on the serial port
    (@state, @dismiss, @info, @pair), each answered with one @reply line,
    and shows the Mac's state instead of the Wi-Fi setup screen while it
    arrives over USB. The menu bar app says "Display connected over USB".
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
